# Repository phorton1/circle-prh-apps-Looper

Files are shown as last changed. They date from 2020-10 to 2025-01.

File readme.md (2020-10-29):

# rpi Bare Metal Looper

This repository contains the source code and other information required to
build a bare metal rPi based Audio Looper.

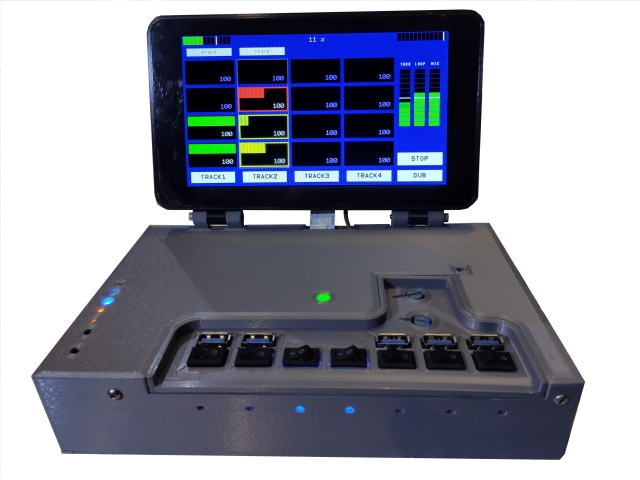
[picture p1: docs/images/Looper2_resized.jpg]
Looper2


Please see the **[docs/readme.md](docs/readme.md)** file for
the [documentation](docs/readme.md) regarding this project.

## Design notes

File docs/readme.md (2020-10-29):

# rpi Bare Metal Looper

**Home** --
**[Hardware](hardware.md)** --
**[Software](software.md)** --
**[UI](ui.md)** --
**[Protocols](protocols.md)** --
**[Details](details.md)** --
**[Looper1](looper1.md)** --
**[Looper2](looper2.md)**

This repository contains the source code and other information required to
build a bare metal rPi based Audio Looper.

Looper2
*Looper2*

This project brings together what, until now, have been multiple disparate parts of the puzzle,
and is a milestone in my **[rPi bare metal vGuitar rig](https://hackaday.io/project/165696-rpi-bare-metal-vguitar-rig)**
hackaday project.

It is based on my prior projects (repositories) which include my fork of the
**[circle](https://github.com/phorton1/circle)** rPi bare metal C++ framework,
and my extensions to it, including a port of the Teensy Audio library to
rPi bare metal, in my **[circle-prh](https://github.com/phorton1/circle-prh)** repository.

The box (my bare metal rPi development environment) also has a Teensy 3.2 board
in it (for serial communications with, and control of, the rPi).  So the
**box** ALSO includes the **[teensyPiLooper](https://github.com/phorton1/Arduino-teensyPiLooper)**
*INO program* which runs on the Teensy 3.2 in it's own repository.
The teensy communicates with, and controls, the rPi, as well as commmunicating with my
3D printed teensy 3.6 MIDI controller pedal, the
**[teensyExpression Pedal](https://github.com/phorton1/Arduino-teensyExpression)**
via serial data.

Together these projects, along with a **Fishman Triple Play** pickup and an **iPad**
running *Tonestack* and *SampleTank* inside of *AudioBus*, form an **actual working rig**.
A set of physical, working hardware, that I can take to a gig, put on the floor, plug in,
and use to play guitar with *effects*, a *midi synthesizer*, and controllable *live loops*
with a user interface (foot pedal) that I like, and that can be somewhat easily extended
and programmed.

Above is a photo of the most recent 3D printed version of the Looper.  There have
been several phsyical iterations of the *box* and the *software continues to
be developed*.

## Organization of Documentation

This *readme* presents some basic concepts and a glossary.  The bulk of
the information about the *Looper* is found in the following separate
readme files and directories:

- **[Hardware](hardware.md)** - Describes the physical hardware
   implementation, which **includes** the specific **sound card**
   I am using, the *Audio Injector Octo*, as well as the **separate teensy 3.2**
   running the *[teensyPiLooper](https://github.com/phorton1/Arduino-teensyPiLooper)*
   INO program.

- **[Software Architecture](software.md)** -
    Describes the overall architecture of **this** C++ program (the *Looper*), which
    runs in an environment that includes **[circle](https://github.com/phorton1/circle)** and
    **[circle-prh](https://github.com/phorton1/circle-prh)** extensions.

- **[User Interface](ui.md)** - Describes the window, buttons,
   and overall **behavior** of this *Looper* from an end-user perspective.

- **[Protocols and Communication](protocols.md)** - Describes, in more detail
   how **communication** with the *Looper* happens, particularly the two way
   communications it has, via serial data, with the
   *[teensyExpression Pedal](https://github.com/phorton1/Arduino-teensyExpression)*.

- **[Implementation Details](details.md)** - Describes
  implementation details of the *Looper* including things like
  the overal **process management** of the program, and details like
  how **crossfading** in looping works.

- **3D Printing** - The folder **"/3DP"** in this repository contains the
  **Fusion360** and **STL** files as well as the *Prusa Specific* printing
  profiles in **3MF** format and **gcode** files*. See the Looper1 and
  Looper2 readme files, below, for more information.

- **[Looper1](looper1.md)** and **[Looper2](looper2.md)** -
  Contains details about the
  contents and construction of the specific instances of the *Looper* box I have
  created, which all generally use the above hardware implementation,
  sofware architecture, and communication protocols, presenting the same user
  interface, but which differ only in their **physical contents**, and ***context***,
  within my overall
   *[rPi bare metal vGuitar rig](https://hackaday.io/project/165696-rpi-bare-metal-vguitar-rig)*
  project.

### Please Also See

- my **[rPi bare metal vGuitar rig](https://hackaday.io/project/165696-rpi-bare-metal-vguitar-rig)**
hackaday project.
- my fork of the **[circle](https://github.com/phorton1/circle)** rPi bare metal C++ framework
- my extensions to circle, including a port of the Teensy Audio library to
rPi bare metal in the **[circle-prh](https://github.com/phorton1/circle-prh)** repository.
- the **[teensyPiLooper](https://github.com/phorton1/Arduino-teensyPiLooper)**
repository which contains the small INO program that runs on the Teensy 3.2
- my 3D printed teensy 3.6 MIDI controller pedal, the
**[teensyExpression Pedal](https://github.com/phorton1/Arduino-teensyExpression)**

## Note on Terminology - "Looper"

The term ***Looper*** is highly overloaded.

It can refer to a piece of software, i.e. a program like *Quantiloop* running on
a consumer computer like an *iPad*, or it can refer to
a dedicated standalone consumer *hardware looper*,
like a Boss Foot Pedal or the looper integrated into a guitar multi-effects device ...
or in my case, it can refer to an *instance of the 3D printed box* I have made that sits on the floor,
***OR*** an *abstraction* of the sum of all the electrical hardware and software
programs running inside that box, **taken as a whole**, or even a more, specific
*part of this software*, the **Looper program** in ***this*** repository, which runs in
bare metal on a *Raspberry Pi*.

Sorry! It's not my fault!

I will generally, in this discussion, use the term *Looper* to loosely refer to the
program, the software, in **this** repository.

In detailed discussions the word
also may occasionally be used synonymously with  a specific **part of *this
software*** ... the *"loopMachine"* as defined in the **Looper.h** and **loopMachine cpp**
files, is sometimes referred to as *"the Looper"* in discusions and/or source
code comments.

At least I can disambiguate a little of it.

When I refer to **Looper1** or **Looper2**, I am talking about the instances
of the 3D printed box I put on the floor.  They are **not** really different in
their basic architecture and/or use of this code.

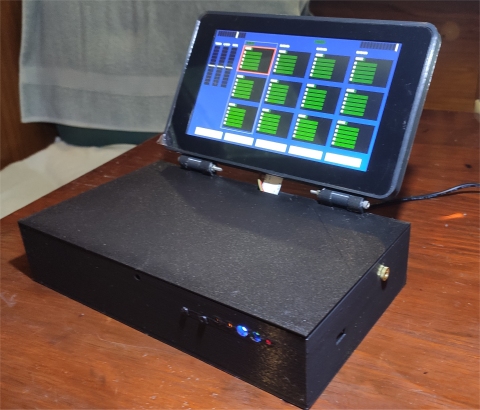
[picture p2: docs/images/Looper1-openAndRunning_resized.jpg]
Looper1-openAndRunning

*Looper1*, running a previous version of this program.

The main difference between *Looper1* and *Looper2* is that *Looper2*
incorporates what was previously an external USB Audio Device, and an external
USB router, ***INTO*** the physical 3D printed box.  This eliminated (at least)
one piece of external hardware from my **rig** and goes to the architecture,
and the realization of a milestone in my
**[rPi bare metal vGuitar rig](https://hackaday.io/project/165696-rpi-bare-metal-vguitar-rig)**
hackaday project.

*But* the difference between Looper1 and Looper2 **is not signficant** in
a discussion of **this repository**, and the program herein.  The same basic
programs run, and the same software, hardware, protocols, and so on, are (were)
used in/with both of them.

## Basic Concepts - Glossary

  The *Looper* consists of four **tracks** that can record and play sequentially, each
  with four *layers* of **clips**, that can play simultaneously at any given time.

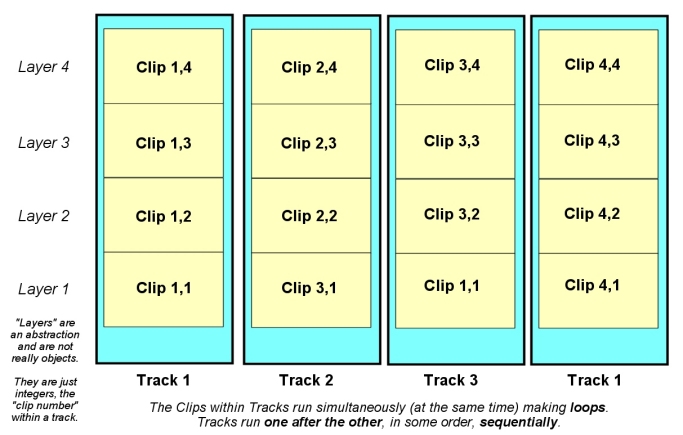
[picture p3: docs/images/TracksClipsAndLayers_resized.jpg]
TracksClipsAndLayers


  This conceptual arrangement of *tracks, clips, and layers* applies not only to this
  program, and it's user interface, protocols and communication, and implementation,
  but also to my other closely related project, the
  *[teensyExpression Pedal](https://github.com/phorton1/Arduino-teensyExpression)*,
  which shares these concepts, and some important **constants** with this program.

  - a **clip** represents a single piece of recorded sound. A clip can be *empty*,
  or it can be *recording*, or it can be *recorded* AND *playing* or *stopped*.
  - a **track** represents upto four clips that are recorded and/or can play together
  synchronously, at any given time.
  - the **layer** of a clip is it's position within a track.

  *The number of tracks and clips are **constants** in the code. 4x4 works well
  for me at this time, with the given screen real estate, and the controllers
  I use, but it is relatively easy to to modify those constants in the code
  to larger, or smaller valus.*

### Clips versus Tracks

  *Clips* play simultaneously, in parallel while *tracks* play sequentially, at
  different times.

  The idea behind *tracks* is that you can have separate **loops** (sets of *clips*)
  for different parts of a song, for example, the INTRO, VERSE, CHORUS, and END
  of a given song. And you can record them, and play them back, in various orders,
  to **build up**, and **perform** a live-looped song.

  Only **one track** is playing, or recording, at any given time.  Generally, when
  a track is playing, *all the clips in it are playing simultaneously*, though each
  can be have different *volumes* and/or be individually *muted*.

  A track is *playing* if any clips within it are playing. A track is *recording*
  if a clip within it is being recorded. A track can be simultaneously playing
  and recording at the same time.

  A track is *running* if any clips within it are recording or playing. The currently
  *running* track is referred to as the **current track**.

  A track is *empty* if all the clips in it are empty.  A track is *stopped*
  if it has at least one recorded clip and is not *running*.

  ### Base Clip, Integer Multiples, and Loop Points

  The first clip recorded in a track is **special**.  It is called the **base clip**,
  and is unconstrained in length.

  **You determine** the length (duration) of the *base clip* when you record the first
  clip in a given track. *Subsequent clips* recorded in a given track **must be** (are) **an
  integral multiple** of the *length* (duration) of the *base clip* in that track.

  A clip **loops** when it is playing and it reaches the end and jumps back to the beginning.
  This is generally called a ***loop point***, and the *loop point* of the *base clip* is
  somewhat special, as it will always be the **next** *loop point* encountered while any
  track is playing.

  Because the clips are integral multiples of the base clip in length (duration), they will,
  generally, synchronize to their beginnings in a predictable manner.  Yet, because you can
  record *different integral multiples* for each clip, they do not necessarily all *loop*
  **together** to the *common beginning* at the same time.

  But eventually they do, as a function of the multiples used. If the numbers are all the same,
  the song will have a rigid predictable structure.  If they are all different, you can build
  songs that don't seem as repetitive to the audience, which take advantage of the different
  clip lengths.

  However, regardless of the actual integral multiples used, algorithmically, eventually
  all clips will cycle back to synchronize to their beginning at some point in time.

### Looper Commands and Pending Commands

  The *Looper* can be issued certain **commands**, for instance to begin recording a track,
  or to begin playing one.

  There is a concept of the **selected track** which can be different than the current track.
  Once again, the currently *running* (recording or playing) track is referred to as the
  **current track**.

  Some *Looper Commands* **may not take place immediately**.

  For instance, if ***Track1*** is *playing* and ***Track2*** is *empty*, and you
  desire to record on Track2, you issue the **Track2 Command** (press the Track2 button) sometime
  while Track1 is playing.   Instead of immediately stopping Track1 and
  beginning to record Track2, the looper will **wait** until it reaches the next
  *loop point*, allowing the base clip (phrase) to complete before stopping Track1
  and beginning to record Track2.

  For that duration, during that window of time, these are called **Pending Commands**.

  While the command is pending, the *current track* is playing, but the *selected track* can be
  said to be **pending** a state change.  Thus, in this example, at the moment you press the Track2
  button (issue the *Track2 Command*), Track2 **becomes** the *selected track* ... different than
  the current one, Track1 (which is *playing*) ... and Track2 is said to have a  *"pending state"*
  ... namely that it is *PENDING RECORDING*.

  This distinction, between the *selected* and the *current* track, and the notion of
  **Immediate** vs **Pending Commands** and a track's *pending state* are important to
  understand, as the are reflected throughout the project(s) in the user interface and
  implementation.

### Layers versus Clips

  This is a relatively minor detail.

  Generally these terms are used somewhat interchangably depending on context.

  The **layer** of a clip is it's position within a track. This is
  an abstraction of a horizontal *slice* of the above diagram.

  There are no *objects* for *layers* in the system, but there ARE objects for
  **tracks** and **clips**.

  In practice, a *layer* is usually just an *integer* that
  identifies a clip within a track, and is also sometimes
  called *the clilp number*.

### Personal Note

I can, **finally**, present the overall architecture
of the system!

It is complicated.

This, for me, is a substantial documentation effort.

I hope to follow it up with some **YouTube videos** demonstrating the *Looper*.

Thanks for visiting this page.  I hope you find it entertaining and/or useful.

-- Patrick

**[Home](readme.md)** --
**Hardware** --
**[Software](software.md)** --
**[UI](ui.md)** --
**[Protocols](protocols.md)** --
**[Details](details.md)** --
**[Looper1](looper1.md)** --
**[Looper2](looper2.md)**

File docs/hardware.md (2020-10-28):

# Hardware - rpi Bare Metal Looper

**[Home](readme.md)** --
**Hardware** --
**[Software](software.md)** --
**[UI](ui.md)** --
**[Protocols](protocols.md)** --
**[Details](details.md)** --
**[Looper1](looper1.md)** --
**[Looper2](looper2.md)**

This readme file describes the physical hardware
implementation of the *rPi Bare Metal Looper*, which *includes* the specific **sound card**
I am using, the *Audio Injector Octo*, as well as the **separate teensy 3.2**
running the *[teensyPiLooper](https://github.com/phorton1/Arduino-teensyPiLooper)*
INO program.

## rPi3B+, AudioInjector Octo, and Official Raspberry Pi 7" Touchscreen

Below shows the basic stack, with the rPi on the bottom, and the Octo on top.

The RCA ports for the Octo have been routed out the back of the box, and the
Touchscreen ribbon cable and power supply positioned to allow the screen to
move on the hinges.

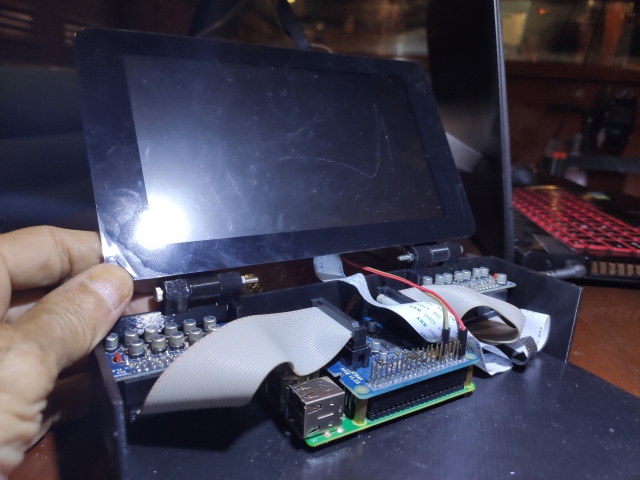
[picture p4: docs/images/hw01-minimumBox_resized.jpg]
hw01-minimumBox


This prototype, early version, shows, essentially, the minimum physical
configuration necessary to run this *Looper* program, or other applications
like this that make use of the *circle-prh* framework. You want a **screen**
of some kind, and a *pointer* input device (the HDMI port and a 40" television,
with a USB mouse were used for most of the development), and a
*high quality sound card* that does *bi-directional* audio.

Getting it down to the **7" touchscreen**, in a box I can put on the floor,
really cleared things up for me.  When I (finally, after more than
a year of development) hooked up the 7" Pi Touchscreen, it basically
worked the first time, within the Circle framework, with no, or
only very minor changes to my code.

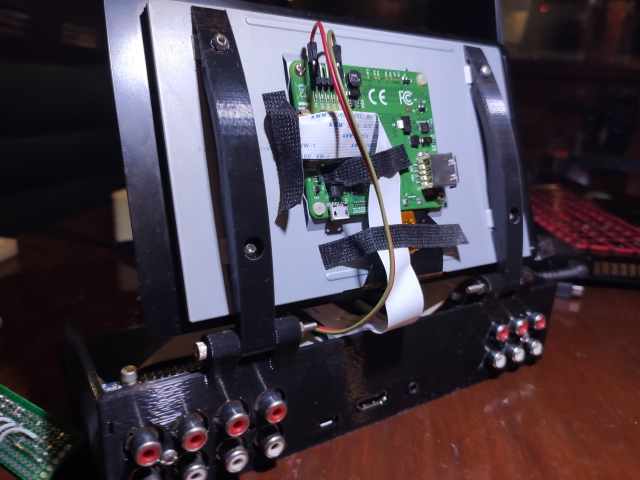
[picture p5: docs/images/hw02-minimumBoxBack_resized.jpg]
hw02-minimumBoxBack


In the above photo you, on the back of the box can see the **8 RCA outputs** from, and the
**6 RCA inputs** to the Octo, and the holes where the rPi micro USB **power** attaches,
and holes for the (unused) rPi HDMI and headphone jacks.

***TODO: I should** publish an analysis of the pin usage by the AudioInjector
Octo, even better yet, a kicad circuit diagram for the rpi, octo, and teensy.
It was hard to ferret out which (other) pins on the rPi I could
reliably use.   In fact, a discussion of I2S might be appropriate here.*

One ***could*** compile the code in this repository, and just *hook the rPi, Octo,
and touchsreen together*, stick the **kernel.img** on an SD card, and it
*would/should* boot and run the *Looper Program*.
 *I am considering publishing a pre-built **kernel.img** "distro"*.

## Teensy 3.2, indicator LEDs, and buttons

I'm not a big fan of swapping SD cards in and out of the rPi. So,
for better or worse, very early on the *circle* project I developed
my own **boot-loader** for the rPi, written in Circle, that can
(among other things), accept a new **kernel.img** over the serial
port, run it, and/or store it on the SD Card for the next reboot.

Historically, I have used a teensy 3.2 as a *smart*
substitute for a typical rs232 usb dongle for serial
(debugging) comms with the rPi.  A hardware serial
port on the teensy is connected to the rPi, and the teensy
serves to forward bi-directional serial text (among other things),
between the rPi and the teensy's *standard* USB Serial port
on my Windows machine.

This architcture (and circuit) goes back to my
[TeensyPi Breakout Breadboard](https://hackaday.io/project/166117-teensypi-breakout-breadboard)
**hackaday** project, and is essentially, with minor changes, a
copy of the breadboarded circuit
from that project.

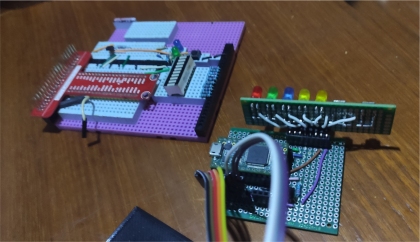
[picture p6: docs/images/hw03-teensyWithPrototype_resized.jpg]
hw03-teensyWithPrototype


Included in this circuit is the ability for the teensy to **reboot the rPi**,
by grounding it's *RUN* (reset) pin.
The circuit uses a **transistor** to control the grounding
of the rPi's *RUN* pin via one of the teensy's GPIO
output pins.
In addition to adding the *header* for the *RUN* pin to the
**rPi board**, I also had to cut a small *notch* into the side
of the **Octo circuit board**, fortunately into the *ground plane*, so that
I could *access* that RUN pin while the Octo is plugged in on top of the
rPi as a *hat*.

#### Hardware relation to Development Environment

This is some more context for the teensyPi evolution and
why this board is part of my *standard application development*
environment.
For what it's worth, my circle **bootloader** interfaces with
a perl program on my Windows machine, the putty-like **CONSOLE**,
that also can work with the Arduino Development Environment,
opening and closing the com port as necessary to prevent
conflicts.

The CONSOLE notices when I have recompiled *kernel.img*.  It tells the
teensy to *reboot the Pi*.  When the Pi reboots, my *bootloader*
runs first (as **recovery.img**) and displays a message (over the serial port)
something like ...

    "hit return to send kernel - will boot existing kernel in 3 seconds .."

... which the CONSOLE program then "sees" and, in response, sends a carriage
 return, and then procedes to the send the kernel.img to the Pi via
 the teensy with a binary serial protocol.
 If the bootloader does not see a carriage return (character 0x0d = 13) in
 three seconds, it just goes ahead and loads and begins running the kernel.img
 from the SD card.

### LED Circuit Board

**In any case**, all of my bare metal rPi projects include this basic
**teensy circuit**, and a couple of *buttons* and some *LED indicators*.

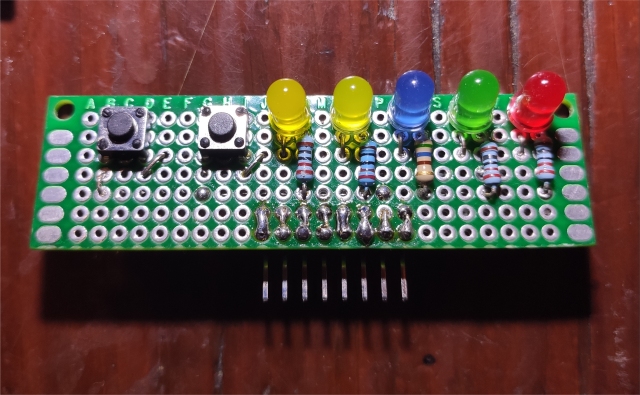
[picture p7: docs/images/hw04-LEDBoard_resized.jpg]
hw04-LEDBoard


The buttons are, from left to right:

- **reboot** the Pi
- put the Teensy in **program mode**

The LEDS, from right to left, are

- **red** - flashes when the teensy is **alive** (copy of the "standard" Arduino/Teensy pin13 onboard led)
- **green** - follows the rPi **RUN** signal where *HIGH* (on) means the rPi
  RUN (reset) pin is "high" (and the **rPi is  running**), or *LOW* (off),
  for brief periods of time, meaning we have brought the rPi "RUN" pin LOW and
  are in the process of rebooting it.
- **blue** - shows the state of the rPi GPIO pin 25, which indicates  that the *std_kernel*
  has **started correctly** .. that
  the *"application"*, the *"program"*, in this case the *Looper* ... the *kernel.img* ...
  has booted correctly  and is **"ready"**. This rPi GPIO pin is **monitored** by the teensy ...
  it is an *input* to one of the teensy's GPIO pins.
- **yellow** - the two yellow LEDs are connected directly to two GPIO pins (12 and 16) from the rPi.
  They *do not go through the teensy*.  Those two LEDs are used by the *AudioSystem* to indicate
  that it is properly processing **I2S** interrupts and buffers, and will flash on and off
  every 90 interrupt/buffers or so (they should flash "on" about 2 times a second).

Please see the [Software](software.md) readme for more info about the **std_kernel** and
the **AudioSystem**

### Teensy Circuit Board

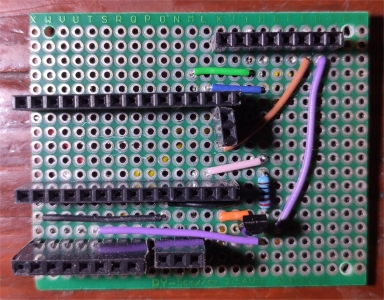
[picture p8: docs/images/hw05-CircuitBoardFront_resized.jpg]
hw05-CircuitBoardFront

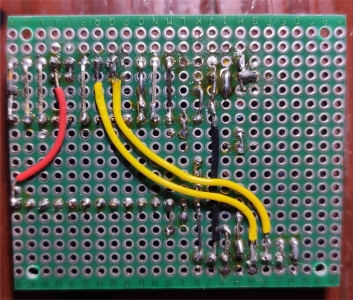
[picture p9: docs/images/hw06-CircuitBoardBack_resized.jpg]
hw06-CircuitBoardBack


The teensy circuit board, in the "top" image above, has connectors for

- 8 pin connector to the **LED/Button Board** at the *top right*
- two rows of 14 pin connectors, and a sideways 2 pin connector, for the **teensy 3.2**
  and it's **program pin** to plug into, in the *center*
- an 8 pin connector to connect to the *rPi* via the **teensy-rPi connector**, at the *bottom left* and
- *next to it*, a 3 pin connector for a second hardware serial port, that is brought out to the
side of the box to a 1/8" jack, that is used to connect to the
*[teensyExpression Pedal](https://github.com/phorton1/Arduino-teensyExpression)*,
as shown below.

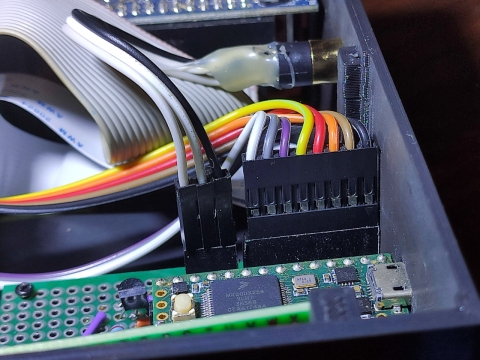
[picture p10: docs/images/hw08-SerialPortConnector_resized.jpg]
hw08-SerialPortConnector


I also had to add a pin to the teensy to bring the *PGM* **program** signal down
to the teensy circuit board, where it can be connected to the button on the LED board.

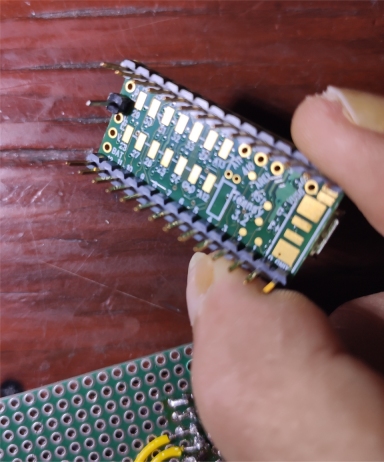
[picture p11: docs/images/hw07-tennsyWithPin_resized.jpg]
hw07-tennsyWithPin


### Teensy-RPi Connector

I kind of like how this connector came out.  I have long struggled with how to
make one-off connections to the top of an rPi stack.

I started by sticking some nylon supports and a **female header** on the pins
from the *Octo*:

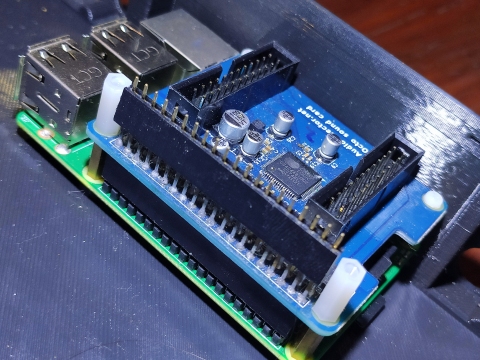
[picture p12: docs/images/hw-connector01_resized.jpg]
hw-connector01


Plunked a small circuit board on top of it:

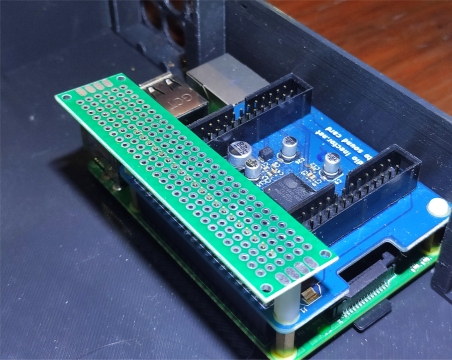
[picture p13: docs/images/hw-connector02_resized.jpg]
hw-connector02


Then cut it to size ....

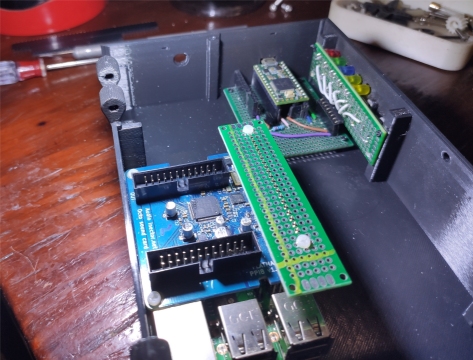
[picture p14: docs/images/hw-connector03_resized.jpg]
hw-connector03


*Note that in the above image you can see the **notch**
that I cut into the *Octo circuit board* to be able to get to the *RUN* pin
on the rPi*.

I then used that circuit board to create a connector between the rPi and the
teensyCircuit board that I can fasten securely with nylon screws.

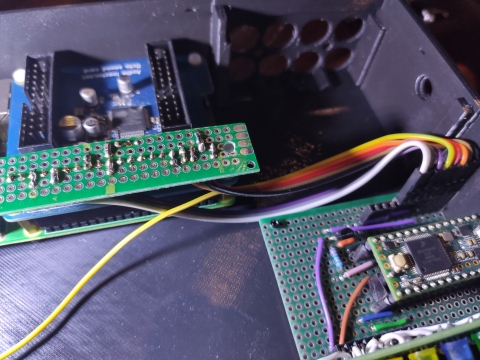
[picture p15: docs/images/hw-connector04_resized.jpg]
hw-connector04


by soldering standard, pre-made wires with *dupont male connectors* on one end,
which I then combined into a **single 8-pin plug** that connect to the *teensy
circuit board*.

The **yellow** wire trailing off to the bottom left in the above photo goes
from the *connector* to the *RUN* pin on the rPi, and then through the cable
to the *teensy circuit board*.

The connector also has two pins (you can't see, on the underside) for the
**power** to the *rPi touch screen*.

## Final (initial) Assembly

Below is a photo of the basic components assembled together in the
initial *instance* of the physical 3D printed box, [Looper1](looper1.md),
running an earlier version of this *Looper* program.

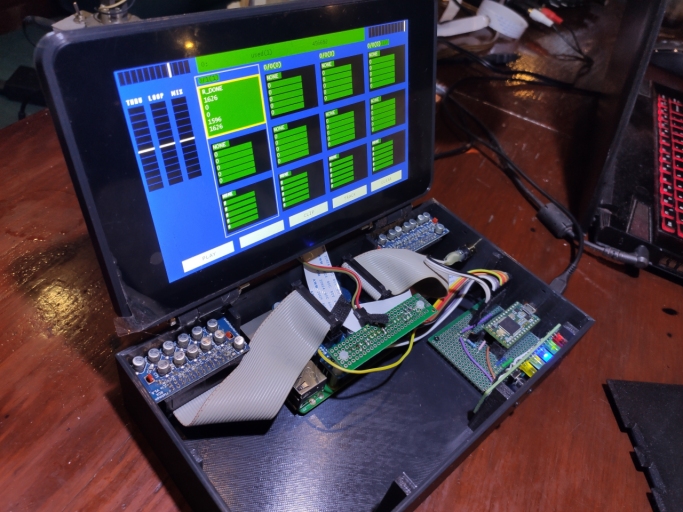
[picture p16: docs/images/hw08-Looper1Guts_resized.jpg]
hw08-Looper1Guts


*--------------- end of hardware.md --------------------*

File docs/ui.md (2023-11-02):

# User Interface  - rpi Bare Metal Looper

**[Home](readme.md)** --
**[Hardware](hardware.md)** --
**[Software](software.md)** --
**UI** --
**[Protocols](protocols.md)** --
**[Details](details.md)** --
**[Looper1](looper1.md)** --
**[Looper2](looper2.md)**

This readme file describes the **User Interface** of the *rPi BareMetal Looper*,
including the window, buttons, and overall **behaviors** presented by the program,
from a user's perpective.

The looper **touchscreen** display shows most of the salient features of the UI
and can be used to control (and describe) most of the *behaviors* of the looper.
*However, there are aspects of the Looper's **behavior** that are not accesible
via the touchscreen and which are only available via **LoopCommands** over the
serial port*.

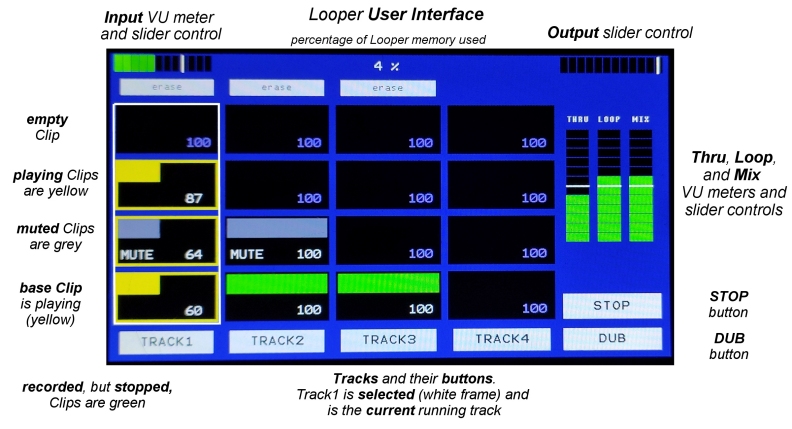
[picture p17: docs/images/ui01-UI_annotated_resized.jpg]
Looper UI


## UI Basics

**VU meters and slider controls** - there are *VU meters* with touch sensitive
*sliders* for the **Input**, **Thru**, **Loop**, and **Mix**.  The final **Ouput**
control is merely a slider ... it does not have a VU meter. You move the *white bars*
on the VU sliders by *touching and dragging* them to adjust the various volumes.

**Buttons** - there are *buttons* for the **four tracks**, the **Stop** and
**Dub** buttons, and, for *recorded* tracks, **erase** buttons above the tracks.
Buttons can be *pressed*, and some can be *long-pressed*, or *pressed twice*
for different behaviors.

- the behavior of the **Track Buttons** will be described in detail, below.
- **Long Pressing** either the *Stop* or *Dub* buttons **stops** and **clears the looper**.
- the **Stop** button does not show until the loopMachine is *running* (a clip
  is *recording* or *playing*).
- A *short click* on the *Stop* button will cause the loopMachine to stop
  *at the next **loop point***, finishing the current phrase (*base clip*)
  before doing so.
- Once the *Stop* button has been pressed (in other words, while the stop command is *pending*),
  the button label changes to **STOP!** (with an exclamation point).  Pressing
  it (again) at this time will cause the looper to **stop immediately**.
- the **erase** buttons do not show until at least one clip is *recorded* or
  *recording* on the given track.  If the track is recording, a *short press*
  on the erase button will **abort** the recording (but keep playing the other
  clips on the track, if possible).
  A *long press* on on one of the erase buttons will **erase the track**, and if
  it is the *current* playing or recording track, will stop the loopMachine.

Clips and Tracks

- The **currently selected track** is highlighted with a *white frame*.
- Clips have a solid frame that matches their *state* and/or that **flashes**
  if they are *pending* a state change.
- Clips that are *playing* or *recording* have a **bar** that moves from left to right
  as the the looper runs.
- Clips that are **solid green** are *recorded*, but *stopped* at this time.
- A Clip with a moving bar that is **red** (not shown above) is *recording*.
- A Clip that is *pending reording* will have a **flashing red frame** (with no bar).
- Clips with moving bars that are **yellow** are *playing*.
- Clips that are *pending play* have a **flashing yellow frame** and a solid green bar.
- Clips that are *pending stops* have **moving yellow or red bars** and a **white flashing frame**.
- Clips that are **muted** are shown in **grey** (looks like grey-blue in above photo)
  and have the word *"MUTE"* in the lower left portion of the clip.
- Each Clip shows it's **volume** as a number from 0 to 127, where *100 means
  unity gain* (no volume change).

Touchscreen on Clips

- **pressing** (clicking) on a clip will *mute* or *unmote* it
- **pressing and dragging up or down** on a clip will change it's volume

Memory Usage

The *Looper* shows the percentage of memory used at the top of the screen.
*As currently implemented, I am conservatively using **128M** (about 1/8th
of the rPi3B's **1GB**) of RAM for the Looper.*  This allows for **1440 seconds**
(about 20 minutes) of recording stereo clips in the Looper for a given song,
which should be enough for most uses. *The constant **LOOP_HEAP_BYTES** in
Looper.h can be changed to increase this if desired.*

### Touchscreen UI versus Serial Midi control

Each of the active UI elements above, the *volume sliders*, the *track buttons*,
the *erase buttons*, the *dub* and *stop* buttons, can also be controlled via
**serial midi data**.  In fact, the touchscreen UI is *implemented in terms of*
**Loop Commands** and various other entry points to the loopMachine, loopTrack,
and loopClip *objects*.

For example, pressing the **Track1 button** causes the **uiWindow** to issue the
**TRACK1** *Loop Command*. to the *loopMachine*.   This *exact same behavior* can
be effected by sending the *serial midi data* for LOOP_COMMAND_TRACK1 to the
serial port of the *Looper*.

To comprehensively describe the **behavior** of the *Looper* it is best to
describe it in *abstract terms* that apply both to the *touchscreen UI* and
the *serial midi protocol* it accepts, especially since there are *aspects
of the Looper behavior that are currently only availalbe via serial midi
data* and which are NOT reflected in the touchscreen UI.

So when we refer to *pressing a button* we are also describing the behvior
when the LoopMachine *responds to* certain **serial midi** "commands" (messages),
and typically, vice-versa.

## Loop Commands

Here is a list of the existing *Loop Commands*.  These are the core functions of the *Looper*.

- **CLEAR_ALL** (corresponds to a *long-press* of either the *Dub* or *Stop* buttons) - stops the
*Looper* if running and clears (**erases**) all tracks and clips.  It also resets all
*clilp volumes* to 100, and clears the *mute* state of all clips.
- **TRACK1-4** (corresponds to pressing one of the four *track* buttons) - will be explained more, below.
- **STOP** (corresponds to the first press of the *Stop* button) - issues a **pending stop** command
  to the *currently running* Track (clips) if any, which will then stop gracefully at the next *loop point*,
  or, if *recording a base clip* to **immediately stop** and save the recording.
- **STOP_IMMEDIATE** (corresponds to the "second" press of the "Stop" button) - stops the
  *Looper* **immediately**, aborting any *recording* currently in progress.
- **DUB_MODE** (corresponds to a press of the "Dub" button) - tells the *Looper* that the
  **next** *TRACK1-4 command* should **record** instead of *playing*
- **LOOP_IMMEDIATE** (not currently reflacted in touchscreen UI) - causes all Clips in the
  currently running Track to **imemdiately** jump back (loop) to their starting points.
- **SET_LOOP_START** (not currently reflacted in touchscreen UI) - sets a **mark point** that
  the Clips will begin looping back to when they reach the next *loop point*.  This lets you
  create a *sub-phrase* **within** a Track, and loop it (without otherwise altering the cilps
  themselves).  This can be used, for instance, at the end of a song, as is common,
  to repeat the last part of the chorus 3 times before ending.
- **CLEAR_LOOP_START** (not currently reflacted in touchscreen UI) - clears any existing **mark points**
  for the selected track. All tracks **mark points** are **automatically cleared** upon any track
  change, and, of course, when the Looper is cleared.
- **ABORT_RECORDING** (corresponds to a *short click* of one of the *erase* buttons while a clip is recording) -
  abort the current recording, if any.  If there are other *recorded* playing clips in the track, the track
  will continue *playing*.  If not, the *Looper* will stop immediately.
- **ERASE_TRACK1-4** (corresponds to a *long click* of one of the *erase* buttons) - **erase**
  the given track, so that it can be re-recorded from scratch.  If the given track is the
  *current* playing or recording track, the *Looper* will stop **immediately**.

### LOOP_COMMAND_TRACK1-4

The **core functionaity** of the looper revolves around
pressing one of the four **Track** buttons (or sending
one of the four *Track Loop Commands* to the Looper via *serial midi*).

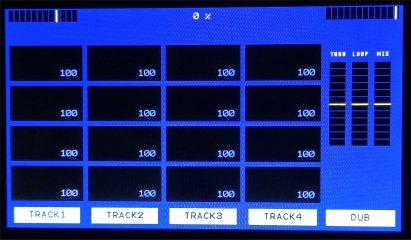
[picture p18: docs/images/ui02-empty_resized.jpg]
empty

*Empty*

The *behavior* (what happens) when one of these commands (buttons) is issued (pressed)
depends on the **state** of the Looper (and the state of the *Dub* button) when the command is
issued.

- From a *stopped or empty looper*, pressing one of the four track button on an
  *empty* track will cause that track to **begin recording** the *base clip*
  for that track.

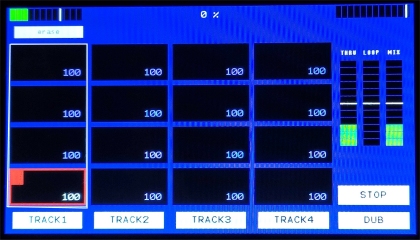
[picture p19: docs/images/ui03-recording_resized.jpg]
recording

*Recording base_clip*, after pressing **Track1** first time

- Pressing the *Stop* button while recording a *base clip* will *determine
  it's length* (duration), save the recorded track and **stop** the Looper immediately.
- Pressing the **same** track button while recording it's *base clip* will
  *determine the clip's length* and **immediately** save the recording and begin
  *playing it* (start *looping*).

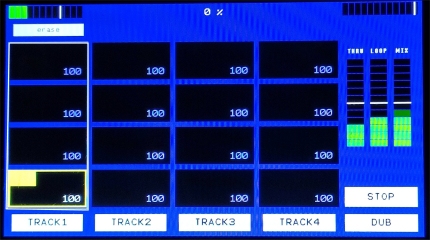
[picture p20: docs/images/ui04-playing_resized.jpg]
playing

*Playing* (looping), after pressing **Track1** second time

- Pressing a **different** track button while recording a *base clip* will
  *determine it's length* and **immediately** save the recording. If the
  **newly *selected*** track is *empty* it will **immediately begin recording**
  it's *base clip*.   If the new track has content, it will **immediately
  start playing**.

Basically, from an *empty or stopped Looper*, or while recording a *base clip*, the
Track buttons (commands) act **immediately**.

- If the Looper is **stopped** (with some *recorded* clips), pressing one of the
Track buttons for a track that has content will cause it to **immediately** begin
*playing* that track.
- Pressing the Track button for an *empty* track on the *stopped* looper
will cause that track to **immediately** start recording the *base clip*
for the track.

### The "Dub" button - Recording a second Clip within a Track

As we pointed out, pressing the **same Track button** while recording the
*base clip*, or pressing a Track button on a track with content while the
Looper is stopped, will cause the Track to start *playing* (looping).

**But what if you want to record another Clip on the track?**

The answer is that you first press the **Dub button** *before* you press
the *TrackN* button.  If the Dub button is lit up (has been pressed)
it turns **orange**, and will take effect on the next Track button press.

So, for example, from an empty looper, to *record( Clip(1,**1**)* and then
to immediately start *playing* Clip(1,**1**) and *recording* Clip(1,**2**), you
would press the following buttons (issue the following *commands*):

- **Track1** - first press *starts recording* the *base clip* for track 1.
- **Dub** - pressing the Dub button sets the **one shot** *dub mode* for
the next Track button press.  The Dub button turns **orange**.
- **Track1** - the second press of the Track1 button **immediately**
starts *playing* the *base clip* WHILE *recording* the **2nd clip** .

The *Dub* button is a **one-shot** button.  It is **not** a *mode*.
Once the command takes effect, the *Dub button is cleared and
will no longer be **orange** (active)*.  You have to press it
*every time* you want to overdub.

### Otherwise, TrackN commands will be pending commands

The *Looper* will enforce the rule that **all clips in a track
have a duration (length) which is an integral multiple of the
base clip duration**.  So, after the *Track1-Dub-Track1* button presses
in the previous section, if you then (more or less) immediately
pressed the *Stop* button, while the base clip
was playing, **the looper would not stop**!

In the below image, within the white framed Track, the **frames around the clips** are **flashing**
yellow and red.

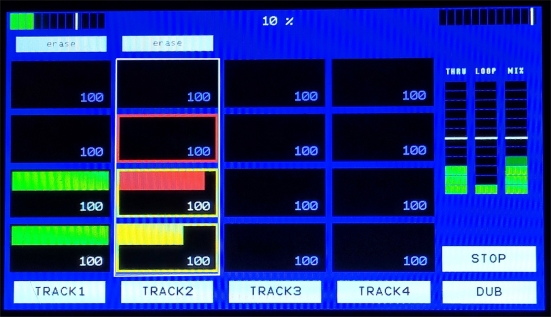
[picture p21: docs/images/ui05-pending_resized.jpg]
pending
 *Pending Clip States*

In the above photo, the yellow *base clip* is playing, the red *clip2* is recording, but *both*
have flashing yellow frames indicating that they are **pending playing** at the next loop point,
and *clip3* is **pending recording** with a flashing red frame.

It will keep *recording* Clip2 until the *loop point*, then it will
start recording the Clip3 the flashing will stop.

This behavior also happens when you click *a different* **Track** button.

*When the base clip is playing* the Looper is said to be **looping** and
all **Track Commands** are executed as *pending commands* ... they take
effect upon the **next** *loop point*.

So, for example, if you have **two recorded tracks** and are playing one
of them, you press the *other track button* well *in advance of* when you
will start jamming over the next track.  This *fire and forget* behavior
is **really handy** so that, except for the *base clips*, you don't have
to be concerned about the **exact timing of your button presses** when
building and jamming over live loops.  You just press the button
any time during the *playback of the base clip* and at the next
*loop point* the Looper changes Tracks, and starts plsying and/or
recording the (clips on the) next Track.

You can even **change your mind** about button presses after performing
them because **only the most recent issued track command will happen
at the next loop point**.   So if you accidentally pick the **wrong Track**,
or decide that you **really don't want to record another clip**, you can
effectively **cancel** or change the command by pressing one of the
track buttons, including the track button for the currently playing
or recording track, ***as long** as you issue the new command
before the **loop point***.

### Loop Commands not reflected in the Touchscreen UI

There are a couple of *Loop Commands* that are not available, at this time, via the touchscreen.
It would be easy to add buttons for them to the *touchscreen UI*, but *I don't really
**use** the touchscreen UI*, except, generally, for *testing the Looper*.
My actual use of the Looper is via **serial data** to and from the
*[teensyExpression **foot** Pedal](https://github.com/phorton1/Arduino-teensyExpression)* which
sits on the floor.

Those *Loop Commands* not available in the UI are:

**LOOP_IMMEDIATE** - causes all Clips in the currently running Track to **imemdiately**
  jump back (loop) to their starting points.   You use this when you want to repeat
  *just the beginning* of a Track one or more times.

**SET_LOOP_START** - sets a **mark point** that the Clips will begin looping back to
when they reach the next *loop point*.  This lets you create a *sub-phrase* **within**
a Track, and loop it (without otherwise altering the cilps themselves).
There are a lot of songs that have a *CHORUS* where, at the end of the song, you
need to **repeat** *part* of the CHORUS, a single phrase, three times, and then you end
the song.

So, for example if you had recorded a **Track** for
*"Mary had a little lamb who's fleece was white as snow"*, and
at the end of the loop you wanted to repeat the *"white as snow"*
sub-phrase three times, then stop, you would:

- **be** *playing* the Track to begin with
- when it gets to the word *white* the first time, you would press the *SET_LOOP_START* button, then ...
- when it gets to the *loop point* (the end of "snow"), the Looper will go back to the
"white as snow" sub-phrase, **instead** of jumping back the beginning of the loop.
- That will start the *second* time through. After that ....
- You let it loop one more time, and then press the *Stop* button **any time** during
the *third*, final, time through, and ....
- the Looper will come to a stop after the word "snow".

The *LOOP_IMMEDIATE* and *SET_LOOP_START* commands (buttons) can be used together
*albeit manually* to **repeat the middle of a Track**.

With *automation*, as takes place in the
*[teensyExpression's](https://github.com/phorton1/Arduino-teensyExpression)*
**songMachine**, interesting pre-programmed sequences of behaviors of the Looper
can be orchestrated that would not otherwise be possible by manually pressing
buttons.

### Other Serial CC "commands" and "notifications"

For completeness, there are also **serial midi** surrogates for the other
functionality of the *Looper UI* including, setting the overall *volume levels*,
and/or the *mute/unmute* state and *volume* of the individual clips, as well
as to be **notified** when the *state* of the looper changes.

Those are defined programatically in **commonDefines.h**

```
// Looper Serial CC numbers             // TE       rPi         descrip
#define LOOP_COMMAND_CC        0x01		// send     recv        the value is the LOOP command
#define LOOP_STOP_CMD_STATE_CC 0x02		// recv     send        the value is 0, LOOP_COMMAND_STOP or STOP_IMMEDIATE
#define LOOP_DUB_STATE_CC      0x03		// recv     send        value is currently only the DUB state
#define NOTIFY_LOOP            0x05     // recv     send        value=number of pending loop notifies
#define LOOP_CONTROL_BASE_CC   0x08     // both     both        RANGED for 0..LOOPER_NUM_CONTROLS the value is the volume control (Looper pedal == 0x67)
#define TRACK_STATE_BASE_CC    0x10		// recv     send        RANGED for NUM_TRACKS, upto 16 tracks, value is track state
#define CLIP_VOL_BASE_CC       0x20		// both     both        RANGED for NUM_TRACKS * NUM_LAYERS, upto 32 total - value is the clip volume
#define CLIP_MUTE_BASE_CC      0x40		// both     both        RANGED for NUM_TRACKS * NUM_LAYERS, upto 24 total - value is mute state
	// this leaves a little space for expansion from 0x60 to 0x7f
```

These are sent, or received, by the *[teensyExpression pedal](https://github.com/phorton1/Arduino-teensyExpression)*
to control the *Looper* and/or change the **state** (the LEDs of the buttons, screen, etc) **of the foot pedal** so
that it shows what's happening with the *Looper*.  For example, the *teensyExpression* has
Track1-4 buttons, just like the *Looper* and those buttons, with addressable colored LEDS,
that can be set to green, yellow, or red, and/or can **flash** just like the *frames around clips
on Looper screen*. This provides a completely separate, yet consistent, floor based (foot pedal),
User Interface to the Looper.

As of v2.11 there is a new LOOP_COMMAND

```
#define LOOP_COMMAND_GET_STATE			0x30	  // NEW the looper will dump all state
	// dumping the state will send
	//      LOOP_STOP_CMD_STATE_CC
	//      LOOP_DUB_STATE_CC
	// 		TRACK_STATE_BASE_CC for NUM_TRACKS
	//		CLIP_VOL_BASE_CC for NUM_TRACKS * NUM_LAYERS
	// 		CLIP_MUTE_BASE_CC for NUM_TRACKS * NUM_LAYERS
	// We do not currently send
	//		LOOP_CONTROL_BASE for LOOPER_NUM_CONTROLS(6)
	// Because TE just always pushes the volume controls
```

Which will send all of the state from the Looper to TE.

*-------------- end of *ui.md* ---------------------*

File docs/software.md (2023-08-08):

# Software Architecture - rpi Bare Metal Looper

**[Home](readme.md)** --
**[Hardware](hardware.md)** --
**Software** --
**[UI](ui.md)** --
**[Protocols](protocols.md)** --
**[Details](details.md)** --
**[Looper1](looper1.md)** --
**[Looper2](looper2.md)**

This readme describes the **Software Achitecture** of the **rPi BareMetal Looper**.
which runs in an environment that includes **[circle](https://github.com/phorton1/circle)** and
**[circle-prh](https://github.com/phorton1/circle-prh)** extensions.

**This repository** contains the *Looper* program, which is a specific *application*, using
specific subsets of the circle and circle-prh repositories (libraries). *Much of this discussion
could be compartmentalized into the other referenced repositories, but for the time being
I am trying to present a single, understandable, overall architectural description of
**how it all works**, rather than trying to minimize my documentation footprint!*

*When this is done, I will **probably** upddate (add) more generalized architectural
discussions to those other repositories,*

## Basic Architecture

The *Looper Application* consists mainly of an **Audio System Device**, the *loopMachine*, and a
single **wsTopWindow**, the *uiWindow*, which constitutes the *user interface*.  The
**loopMachine** has four (4) **loopTracks** which each own four (4) **loopClips**.

Likewise the **uiWindow** has four **uiTracks** which each have four **uiClips**.

Between the *loopMachine* and the *user interface* there is an abstraction layer of
the *loopMachine* called the **publicLoopMachine**, with it's corresponding **publicTracks**
and **publicClips**.  The *User Interface* **can only see** the *publicLoopMachine*.  It has no
visibility of, or direct access to the *loopMachine*.

The **loopMachine** runs all the time as an *interrupt driven audio system device*, therefore
it is very important that it runs quickly, and in a known state. The objects
in the *loopMachine* have *API's* that are visible to each other as appropriate to implement the
core behavior of this interrupt driven *Looper*, but that are **not** visible to the UI.

The **pubicLoopMachine** is a set of pure virtual base classes that are implemented by the
loopMachine, and available to the UI, that carefully grants **readonly** access to
the state of the loopMachine, with **specific methods** (*entry points*) that the UI
can call, like the ***publicLoopMachine's command()*** method to *change it's state*, to cause
the *loopMachine* to actually **do** something.

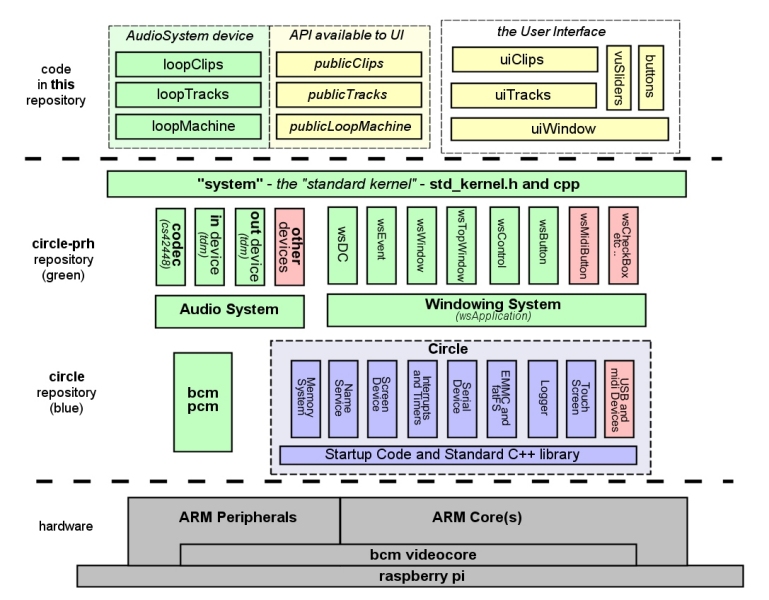
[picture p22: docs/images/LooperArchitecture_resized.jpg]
Looper Architecture


Below the top dashed line you see the **circle-prh** and **circle** libraries/repositories.  Some
of the boxes in that diagram are in **red**, indicating, and implying, that there is (much)
code in those libraries that does not happen to get used in this specific application.

The other boxes are **examples** of the specific objects and kinds of code that are used
from those libraries, and do not reflect an *exhaustive* list of the specific objects and
code.  But this diagram does show the most important parts of those libraries to this application,
including the use of three of the specific *"prh*" subsytems (subdirectories):

- the **Audio System**, the objects within (above) it, and below it, the important common **bcmpcm** (cpp & h) object.
- the **Windowing System**, and some of the objects within it, and ...
- at the top, the (overloaded name) **system** subdirectory, which contains the
basic framework (*"glue"*), the *standard kernel*, in **std_kernel.h and cpp** that
ties everything together into *applications* written in this environment.

By the way, when all of this code is built (compiled and linked) it results in a *single file*
named **kernel.img** (the exact name depends on the rPi model), which is then copied (somehow)
to the SD Card on the Raspberry Pi, and which is then subsequently booted.  In other words, every
complete *application*, at this time, in this sytem, is built and run as an
**operating system kernel** in common parlance. *There is **no linux** or other
operating system involved*. That's why we call it **bare metal**!!

**ALL of the code** running on the rPi is in these three repositories.

In **circle** the most important objects (classes) necessary to build a complete
program (**kernel.img**) in this system, includes (but is not limited to):

- the **CMemorySystem** - initializes the rPi memory system (MMC)
- the **CDeviceNameService** - provides for named devices
- the **CScreenDevice** - the HDMI or rPi screen device
- the **CInterruptSystem** and **CTimer** - basic interrupts and timers
- the **CSerialDevice** - the rPi UART driven serial port
- the **CEMMCDevice** and *addOn* **FATFS** classes for the SD Card
- the **CLogger** - a generalized Logging device to Screen or Serial ports
- the **CTouchScreen** - the VideoCore, or other, TouchScreens

Once again, to point out, I included some **red** boxes in the diagram to specifically
show that we are **not** using all of the code in the circle-prh and circle libraries.

For example, in **circle-prh** we are not making use of many of the *AudioSystems*
devices that are availble, including **mixers**, **reverbs**, and so on,
nor many of the **WindowSystem** objects that are available like **checkboxes**,
**midi buttons**, and so on. Nor are we inluding anything from entire *"prh** subdirectories,
including the **devices**, **lcd**, and/or **bt** subdirectories, in this specific application.

In fact, my intention was/is to keep the *Looper* program as simple as possible.

In *circle* I specifically am *NOT* using the circle **USB** capabilities (for performance
reasons), nor the **USB Midi Device** that it makes available.  There is a *ton* of other
functionality in circle that I am not using ... including any of it's *sound devices*,
or it's entire approach to audio, either of it's two available *entirely different*
addon *windowing systems*, or many of it's other *add on* extensions. Above is merely a list
of the most important circle objects that we **are** using in this build.

Finally, at the bottom, below the lower dashed line, is the **hardware** itself, abstracted
in this diagram to the notion that there are one or more **arm cores** (cpus) available to us,
depending on the model of raspberry pi used, but that all of them include
the **arm peripherals** which are the low level programming API's and protocol to things like
*I2S* and *UARTs*, supported by the chip, and that all of **that** runs on top of the
(mysterious and undocumented) Broadcom **VideoCore**, which is a separate CPU on the
**Raspberry Pi** board.

## The BCM_PCM and the AudioSystem as used in this application

Perhaps the most important object in the *AudioSystem* is the **bcm_pcm** object (h and cpp files).

The **bcm_pcm** provides an interface to the BroadCom *PCM Peripheral*, and implements
a generalized approach to the **I2S** (*Inter IC Sound*) protocol to interface the **rPi** to
various **sound cards**. It uses **DMA** to send and receive *buffers* of sound data
to and from the sound card based on **interrupts**.

In this application we are using the *AudioInjector Octo* sound card.
The *Octo* is a 6 (six) input, 8 (eight) output sound card.

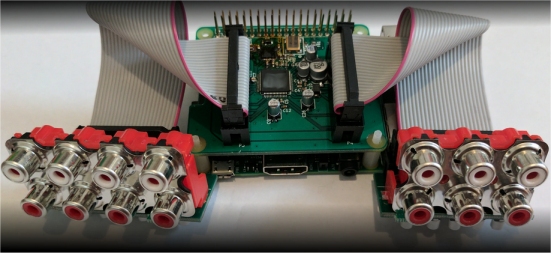
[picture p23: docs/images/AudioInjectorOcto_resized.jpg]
AudioInjectorOcto

*AudioInjector Octo sound card*

In this application we are only using two
of the input channels and two of the output channels (the *Looper* is **stereo**),
but underneath the hood, the system is *processing* the data for all 6 input channels
and 8 output channels.  The *Octo* runs as a (pseudo) **TDM** (time division
multplexed) device. We are running it at **44.1 khz** with **16 bit** samples,
and a **buffer size** of 128 samples **times** eight (8) channels.

The *initialization* of a sound card takes place in the **control** device, so in
this case the, with the cs42448 based *Octo*, we are using the **control_cs42448**
(h and cpp) device in our system.  When using this control device, you also need
to use the **AudioInputTDM**  and **AudioOutputTDM** devices from the *AudioSystem*.

The *bcm_pcm* generally handles the buffering of input and output data, using *DMA* on
an interrupt driven basis.  When it has received an input buffer, it then proceeds
to pass it to the *Audio System*, either directly in a single core system, or via
an inter-processor interrupt in a *multi-core Circle* application.   The *Looper*
is built as a multi-core appclication running, at this time, on a **raspberry Pi 3B+**.

The *bcm_pcm* (and all rPi interrupts) runs on **core 0**.

The *application* registered the specific *control* and *TDM* input and output devices
with the AudioSystem. It also registers the *loopMachine* (which is, itself, a stereo
*Audio Device*) during **setup()**. The AudioSystem runs on **Core1**.

When the bcm_pcm *hands off* the buffer to the AudioSystem, it then,
in turn, passes it to the registered **AudioInputTDM** device.

The **AudioInputTDM** device then de-multiplexes the data into a set of per-channel
buffers. Plese note that at this time, in this application, at this level of
processing, the system is **actually** processing the entire set of *6 input channels*.
When the *input_tdm* has prepared the buffers, it in turn passes them to the
back to the AudioSystem, which passes them to the registered *loopMachine*.

This *loopMachine* is only interested in, only uses, the first *stereo pair*
of input buffers available to it.  It works with those buffers, possibly
*recording them* by copying them off into RAM someplace (in *looperClips*), and
produces the final stereo output pair of buffers by processing the input buffer
**thru** to the output, applying volume levels and noting the minimum and maximum
values in the buffer(s) for the vu meters. It also possibly mixes previously
recorded buffers (**playing** *looperClips*) into the stream, likewise
applying volume levels and noting values for the vu meters,
finally resulting in a pair of **output** buffers that it (the *loopMachine*)
passes back to the *AudioSystem*.

The *AudioSystem* then passes those final buffers to the **AudioOutputTDM** device
where that object multiplexes the data back into I2S buffers, and provides those back
to the *bcm_pcm* for output to the sound card via I2s.

## Application Initialization and basic UI Framework

In this *typical* application, the **standard kernel** handles (makes) the
various calls to the AudioSystem and WindowSystem (does the *process management*
in the system) to orchestrate the overall behavior and functionality of
the program.

With regards to the *WindowSystem* (the **user interface**), the system first calls a
specific method, **wsApplication::Create()** that the *application must supply* that
**instantiates** the user interface.

**This** application (*Looper*) merely instantiates the *uiWindow* object
with the following small piece of code in **app.cpp**:

```
void wsApplication::Create()
{
    LOG("wsApplication::Create(%08x)",this);
    new uiWindow(this,ID_WIN_LOOPER,0,0,getWidth()-1,getHeight()-1);
}
```

The uiWindow then creates the objects within it (the *uiTracks, uiClips, vuSliders*,
and *wsButtons*) and returns.

Looper UI

wsWindows, and objects derived from them, implement an **onDraw()** method that the
system can call.

Once the *Top Level Window* is intantiated, the *system* ensures that it is drawn
on the screen at the correct time (by recursively calling wsWindow's **onDraw()** methods),
and that it (the top level window) receives *wsEvents* (like EVENT_CLICK) via it's
**handleEvent()** method.

*wsWindows* also have a method called **updateFrame(()** that is called frequently
(30-100 times a second or more) separate from events, that constitutes the **ui thread**.

The *uiWindow* uses calls to it's *updateFrame()* method (which it in turn passes
to *updateFrame()* methods on the *uiTrack* and *uiClip* objects) to query the
*pubicLoopMachine* and corresponding *publicTracks* and *publicClips* for state
changes that must be reflected in the user interface.

For example, a uiClip displays a "moving" *"bar"* that represents a
recording or playing track in progress, that changes, and must be redisplayed, as
the recording or playback progresses, based on the value of **publicClip's**
*getRecordBlockNum()* or *getPlayBlockNum()* methods.
Likewise, uiTrack displays a frame around the the *selected* track (based on
calls to **publicTrack's** *isSelected()* method, and uiClip shows **pending commands**
by flashing the frame around a uiClip on and off in various colors (red for *record*,
yellow for *play*, and white for a pending *stop*) based on the **publicClip's**
*getClipState()* method, combined with the value returned by the **publicLoopMachine's**
*getPendingCommand()* method.

Note that windows do not draw themselves from within the *updateFrame()* method.
They merely **update** their state, and if they need to be redrawn, they set their
own **WIN_STATE_DRAW** bit, and at a later time, in a coordinated manner, all windows
with that bit set will be redrawn (have their *onDraw()* methods called) by **the system**.

## Audio System Initialization and Framework

As noted in the **[circle-prh](https://github.com/phorton1/circle-prh)** repository,
this **port of the teensyAudio system to the rPi** exposes an *Arduino-like* approach
to the instantiation and initialization of *AudioSystem* objects.  AudioSystem objects
can be *statically* or *dynamically* allocated.

The **system** (*std_kernel.cpp*) calls the static global **setup()**
method once at the start of the program.

*There is also a familar Arduino-like static global **loop()** method,
that runs on the AudioSystem thread (*Core1*), and IS called, but this method is
generally left **empty** in my typical applications, as we want the AudioSystem
to run un-impeded.  Remember that the **UI** (WindowSystem) runs on a **different
core**.*

The AudioSystem *setup()* method is in the file **audio.cpp**,
and looks something like this:

```
#include <audio\Audio.h>
#include "Looper.h"

AudioInputTDM input;
AudioOutputTDM output;
AudioControlCS42448 control;

loopMachine *pTheLoopMachine = 0;
publicLoopMachine *pTheLooper = 0;
    // static global pointers to objects available, by convention, with
    // externs in Looper.h, to the loop machine itself, or to the
    // more limited "public" UI version of the object

void setup()
{
    pTheLoopMachine = new loopMachine();
    pTheLooper = (publicLoopMachine *) pTheLoopMachine;

    new AudioConnection(input,      0,      *pTheLooper,       0);
    new AudioConnection(input,      1,      *pTheLooper,       1);
    new AudioConnection(*pTheLooper,   0,      output,         0);
    new AudioConnection(*pTheLooper,   1,      output,         1);

    AudioSystem::initialize(200);

    pTheLooper->setControl(LOOPER_CONTROL_OUTPUT_GAIN,0);
    pTheLooper->setControl(LOOPER_CONTROL_INPUT_GAIN,0);
}
```

Though there are other things in the *Looper's* **audio.cpp** file, like
**#defines** that let you choose the other available *Codec* and *Input/Outtput devices*,
and the fact that the **setup()** method, after executing the above code,
then goes on to *fade up* the input and output gains to their default values,
the above is, more or less, all that is necessary for an *application* to instantiate
and initialize the *AudioSystem*.

#### **loopMachine specifics - commands and pending commands**z

The *system* will call the loopMachine's **update()** method once per the *interrupt cycle*
of bcm_pcm-I2S *input buffers*. The loopMachine  processes those buffers, and at the end of
update(), calls it's own virtual **transmit()** method to *"send them back"* to the
AudioSystem, who will then eventually send them to the *AudioOutputTDM* device, which
in turn multiplexes them and gives them to the *bcm_pcm* to send out to the sound card
via *I2S* on the next output interrupt.

The other *main input to the loopMachine* is (by the uiWindow calling)
the *publicLoopMachine's* **command()** method.

The *command()* method will be called by the UI, typically in response to a
button press, but also, in detail, in response to the uiWindow receiving some
**serial midi data** via the rPi SerialPort, which it *monitors* in it's
**updateFrame()** method.

One way or the other, though, to the UI and external clients, *the (public)LoopMachine is
essentially an interrupt driven black box state machine*.  You merely pass commands to it,
for instance to *clear* it, or to *begin recording a clip*, but most of those commands
are handled completely separate from the basic loopMachine **interrupt driven update()**
method, via the **pending command** mechanism.

Remember that the UI is running on one core, and the Audio System on a different one.

We want to make sure the AudioSystem (which is already an interrupt handler)
is not itself *interrupted* or held up in any way.   So, when commands are issued
to the *loopMachine*, they usually result in a **pending command** that
will be processed in the loopMachine's *update()* method at some later
time, typically at a **loop point**.

*Some* commands, like *CLEAR LOOPER* and *STOP IMMEDIATE* are handled immediately.

A list of the commmands that can be issued to the *Looper* can be found in
**commonDefines.h**.

#### **loopMachine controls - volumes and vu meters**

Another set of entry points into the publicLoopMachine are a set of API's
that allow the UI to query and adjust the overall volumes used by the Looper.  There are five
controllable global volumes on the loopMachine.

- **INPUT** - controls the basic (hardware) input gain of the Codec
- **THRU** - controls how much of the input is passed through to the *mix*
- **LOOP** - how loud is the loop (any playing *cips*) passed to the *mix*
- **MIX** - a volume control for the *mix* before passing the buffer(s) to the ...
- **OUTPUT** - hardware output gain of the codec

Most of these volume controls have an associated **meter** API on the loopMachcine
that allows the UI (the *vuSlider* objects) to obtain the minimum and maximum
levels of the given control, over some interval of time, and to display it.

All of the above controls *except the final OUTPUT control* have **meter APIs**
on the publicLoopMachine, associated with them. *We cannot **meter** (monitor) the actual
final OUTPUT values as that takes place in hardware!  But for all of the others,*
the loopMachine::update() method *remembers* the high and low values for
each stage as it processes each buffer, and presents an API
for the UI to read and reset them.

Those methods are *polled* during the **vuSlider's** *updateUI()* method.

Note that, as it does for *Loop Commands* sent via serial midi, the **uiWindow**
also monitors the serial port for **serial midi CC messages** that correspond
to each of the above controls, and converts those messages into the appropriate
calls to the aforementioned loopMachine API's.

#### **loopClip - volumes and muting**

The **publicClips** present an API that allows the UI to obtain,
and/or modify the Clip's individual **volume** level and/or to **mute** it.

A clip is **still running** (playing or recording) EVEN IF IT IS MUTED.

The clip volume and mute state are *applied* when each clip makes
it's contribution, if any, to the *output buffers*, in it's own **update()**
method.

As with the other **serial midi** stuff, the **CC's** for affecting
the individual volumes and mute states is coded in the *uiWindow*,
with constants in *commonDefines.h*,
which maps them from serial midi messages into specific method calls on the
*publicClip* objects.

#### **Serial Midi Notifications** also happen in the uiWindow objects

As the loopMachine is running, changes to it's state (the machine,
tracks, and/or clips), as we've seen, must necessarily be reflected in
the corresponding UI objects.

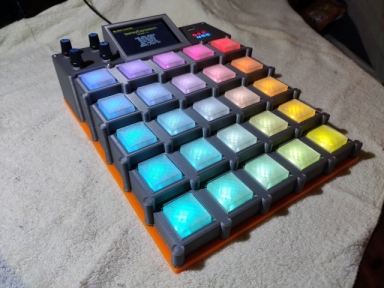
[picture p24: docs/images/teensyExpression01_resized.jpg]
teensyExpression01

*teensyExpression midi controller pedal*

Furthermore, serial clients, like the
*[teensyExpression Pedal](https://github.com/phorton1/Arduino-teensyExpression)*,
in addition to wanting to **control** the loop machine, by *sending* serial
midi commands to the Looper, want to be notified about changes to it's state,
by *receiving* serial midi.  For example, the pedal want's to know
*when a loopPoint is reached* in it's implementation of the **songMachine**,
and it wants to know when a *track state* changes (*empty*, *recording*,
*playing*, or *stopped*) and/or if there is a currently *pending command*.
so that it can **light up** the *track buttons* in various colors, and
**flash** them for pending commands.

Therefore, when the **UI objects** (uiWindow, uiTrack, and uiClip) notice
that something has changed (in their updateState() methods), they typically
will *also* send out a **serial midi notification** message, which the client
device (the **teensyExpression pedal**) can then use to keep track of,
utilize and to display, what's happening with the *Looper*, in real time.

Once again, the specific **CC numbers** and *parameter values* for these notification
methods are defined in **commonDefines.h** (which is  denormalized to, and
included in the *[teensyExpression Pedal repository](https://github.com/phorton1/Arduino-teensyExpression)*.

## Other General Notes

#### **Other sound cards could be used**

I chose the *AudioInjector Octo* because, to me, it sounded the best of any
audio cards I tried to work with on the raspberry pi.  The fact that it has
a whopping 6 inputs, and 8 outputs, is viewed merely as a *bonus*.

The *AudioSystem* also currently has support for the *AudioInjector Stereo* in
**control_wm8731.h and cpp** as well as the *teensyAudio Card* in **control_sgtl5000.h
and cpp**, and either of those *should* be usable with this *Looper*.

It should also be relatively straight forward to implement *other sound cards* into
this system and application.  I am just not aware of many others that do both **input**
and *output*. *If you know of a **great** sound card that does both input and output on the
raspberry Pi, I would like to hear about it!*

#### **This is a general *Audio Application* development platform**

This *Looper* project is but one of the possibiities that could be written
using this set of libraries. Especially to the degree that the *AudioInjector
Octo* presents 6 inputs and 8 outputs, it could also be viewed as a
**audio application development platform** for developing other
rPi based audio "devices".

A couple of examples come to mind.

First, please note that the rPi3B+ has **four cores** and that at this time
we are only using *three* of them.   **Core0** is dedicated to interrupt processing
and inter-process communications.  In this program Core0 doesn't actually *run* anything ...
it just waits for, and processes, interrupts.
The *AudioSystem* runs on **Core1**, and the *WindowingSystem* (UI thread) runs
on **Core2**.

So, at this time, **Core3** is unused, and available.

It might (*should*) be possible, and practical, to implement, for example, a set
of **guitar effects** that run on Core3, that do not impact the current behavior
or timing of this *Looper*.

And/or, within this basic framerwork, by *expanding* the *loopMachine*
and/or adding objects (like the existing *Audio System* **reverb** and/or **mixer**
devices) to create a Looper which, itself has *effects*, and which works on, and with,
the entire 6x8 (six by eight) set of inputs and outputs, for example, to let you
**separately** loop your **voice** from looping your **guitar** .. or to even have
separate *loop channels* for every member of the band.

The point of this section is that although it works, and I consider it part
of my *rig*, this *Looper* project is **really** just an example of the kinds
of things you *could* build with this system.

*------------- end of softare.md ------------------*

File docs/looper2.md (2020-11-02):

#  Looper2: the latest instance of the box

**[Home](readme.md)** --
**[Hardware](hardware.md)** --
**[Software](software.md)** --
**[UI](ui.md)** --
**[Protocols](protocols.md)** --
**[Details](details.md)** --
**[Looper1](looper1.md)** --
**Looper2**

This readme file describes the most recent instance of the **phsycial 3D printed** box
representing the *rPi Bare Metal Looper*, it's specific contents, and a bit
about how it fits into my overall *[rPi bare metal vGuitar rig](https://hackaday.io/project/165696-rpi-bare-metal-vguitar-rig)*
project.

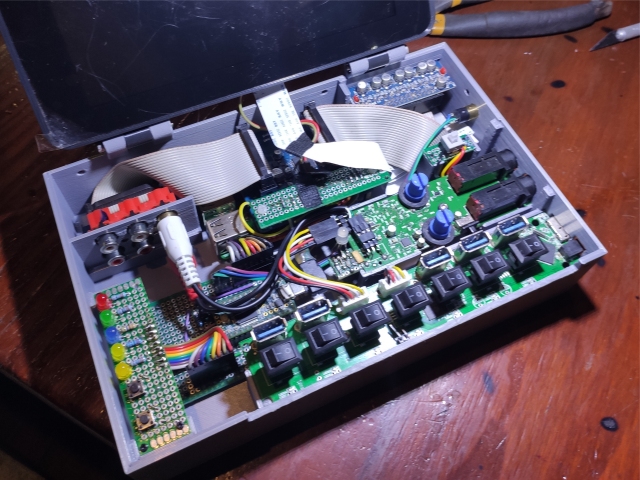
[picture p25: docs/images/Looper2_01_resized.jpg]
Looper2_01


This readme can be viewed as **inheriting** certain information and content presented in
the *[Looper1](looper1.md)* readme.  For instance, in 3D printing **this** box, I used the same
**frame for the rPi official 7" touchscreen** that I had already printed for **that** box, and
it also contains the same basic core components, the **sound card** (*Audio Injector Octo*)
and **teensy 3.2**, as were in that box, ableit in a sligthly different physical configuration.

There was enough room left over in the [Looper1](looper1.md) box that I figured I could
incorporate the **iRig2 HD** USB audio card, and the 7 port **usb hub** from my previous
*(hackaday) [SynthBox1](https://hackaday.io/project/168197-synthbox-1) box (project).* within
this box, and eliminate a piece of hardware and several cables from my live rig.

### Stuff from previous ["SynthBox1"](https://hackaday.io/project/168197-synthbox-1)

I had previously modified the circuit board from an inexpensive **7 port USB hub**
to replace two of the USB port connectors with dupont connectors.  For this
project, I removed those two *dupont* connectors and replaced them with more
secure, real, white *PCB connectors*:

Looper2_11
Looper2_12

Also from that project I took the **iRigHD2 board** which I had *already modified* to
replace the 1/8" audio jack and micro USB connectors with *male headers*,
bring the *Activity LED* to the the "top" by adding a small circuit board extension,
and by adding a *Pad Switch* to allow me to change the impedance of the 1/4 input plug
to work better with my guitar.

Looper2_13 *modified iRigHD board*

Looper2_14 *iRigHD2 Activity LED addition*

Looper2_15 *iRigHD2 Pad Switch Addition*

### Assembly

I then measured everything, did the 3D design work in fusion, and printed a new **box**
for this version.  Notable changes from the previous box include:

- The **RCA inputs** are now internal to the box ... as the audio output of the *iRigHD2*
now connects directly to the *Octo* audio inputs.  This **eliminated an external cable**.
- I added a separate **USB Port** for the
**[teensyExpression pedal](https://github.com/phorton1/Arduino-teensyExpression)**
- The **Teensy Circuit Board** was moved to the left side of the box.   This necessitated
adding a micro-usb "extension" port, as well as reworking the *LED Display board* and
*rPi-teensy connector*
- **supports** for the iRig2HD, the USB router, the Pad switch board, and the new location
of the teensy board and LED display board.

The *3D printing files* (fusion, STL, and gcode) for printing this bo
can be found in the **/3DP** folder of this repository.

Looper2_21

Below is an image showing the removable *SD Card Cover* that lets you swap the SD card
out of the rPi without disassembling the box, and another image showing the new location
of the *Teensy* circuit board along with the *teensy-rPi connector* (from which I have
de-soldered and removed the wires in preparation for modifying them to fit the new
configuration).

Looper2_22
Looper2_23

The first image below shows the *reworked rPi to Teensy connector* on top of the Octo card, and
connected to the teensy.  Also in that image you can see the attached *micro USB extension for the Teensy*
and the *USB Port extension* waiting to be connected to the *USB Hub* and let me plug the
*teensyExpression* pedal into the side of the box.

Looper2_24
Looper2_25

The second image above shows the box with the addition of the *LED Display Board*
(and it's new cable connector), with the *iRig2HD and USB Routers* installed, and you
can see the *1/8 jack* for the additional teensy serial port.

Below is the box with all the *guts* installed, except for the Octo *RCA
connectors* and the *screen*.  It it you can see two 3D printed pieces that
make up the *top* of the box.

Looper2_26

The two parts of the top are glued together with superglue, and then
(after drying) the assembled top is attached to the box with 3mm screws
so it can be removed later as needed.

### Connections

In the below image you can see the connections on the right side
of the box.

Looper2_31

From left to right in the above image, the connectors are:

- **5V** power supply (input) to the USB hub.
- **USB Hub Connector** to the iPad
- the white cable plugged into the **USB Port** to the *teensyExpression pedal*
- the **1/4" Guitar** input
- the **Teensy micro USB connector** and above it,
- the **1/8" Serial Port**,  also to the *teensyExpression pedal*

The USB hub ends up **powering** the *teeenyExpression pedal* and the *iRigHD2*.
The actual *teensy* in **this** box (and the *rPi*) are both powered by the rPi
power connector (not shown here) on the **back** of the box.

*A future iteration of this box will likely consolidate the power supplies into
one connector*.

In the above image, we are **not using** the *left 1/4 jack* which is an additional output from the iRigHD2,
and the *Teensy micro USB connector* is only used during development to communicate
with, and program, the teensy and rPi from my **development machine**.

Looper2_32

And finally, in the above image you can see the full box, running the *Looper* program.
To the *left* you have the vertical column of **LEDs and buttons** for the teensy and rPi,
showing that the program is running correctly, the *center* **iRig Activity LED** (green)
shows that sound is coming into the iRigHD (and not overdriving the inputs, which would cause
the LED to turn red), and a square hole where you can insert a tool to change the **Pad Swtich**.

On the "sunken" portion of the top, that leaves the 5 available *USB ports*, the *7 switches* that control them
and the two gain control *potentiometers* (input gain and output volume) for the iRig.   I have marked
where I like those two pots with a magic marker.

On the front of the box, there are the seven LEDs indicating power to the USB hub ports.
The two blue LEDs show that the power is "on" for the USB to the
*iRigHD* and the *teensyExpression pedal*, respectively.

**TODO: Want an image of the whole rig, with teensyExpression and iPad, here**

*---------------------- end of Looper2.md ------------------------

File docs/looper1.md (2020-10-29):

# Looper1: the initial instance of the box

**[Home](readme.md)** --
**[Hardware](hardware.md)** --
**[Software](software.md)** --
**[UI](ui.md)** --
**[Protocols](protocols.md)** --
**[Details](details.md)** --
**Looper1** --
**[Looper2](looper2.md)**

This readme file describes the first instance of the **phsycial 3D printed** box
I created for the *rPi Bare Metal Looper* and how it fits into my overall
*[rPi bare metal vGuitar rig](https://hackaday.io/project/165696-rpi-bare-metal-vguitar-rig)*
project.

As it came first, the subsequent *[Looper2](looper2.md)* can be viewed to **inherit**
information and content from this instance.

Both make use of, and contains, the general core
*[Hardware](hardware.md)* implementation of the *Looper*.

The **Fusion360** and **STL** files as well as the *Prusa Specific* printing
profiles in **3MF** format and **gcode** files* for this box are in the
**"/3DP"** folder in this repository.

Looper1-openAndRunning

### Looper1 Box, Teensy & LED board, rPi and Octo

Looper1_01

The box **printed** without supports.  The first thing added is the **teensy circuit board** which
has holes for four tiny *self tapping screws*.  Then you insert the 3D printed **switch extensions** into the box,
insert the the **LED board**, and secure it with two more screws.

Looper1_02
Looper1_03

The **rPi3b+* is attached to the box with four **brass supports** with
*3mm threads* that screw into the box.  On top of that, the **AudioInjector
Octo** card is added with *nylon supports and screws*.

Looper1_04
Looper1_05

### "Official rPi" Touchscreen Case and Bevel

The case for the **touchscreen** is also used in [Looper2](looper2.md).

I *removed the four supports* that came with the official touchscreen
and replaced them with **shorter** nylon supports, connected the
**ribion and power cables** and secured the ribbon cable with
some black adhesive tape.

Then the **bevel** is set into place (but not screwed down yet) and
the **back** is attached with four *nylon screws*.  The *back* locks
the *bevel* into place

Looper1_06
Looper1_07
Looper1_08
Looper1_09

Then **hinges** are added with four *3m metal screws* which provides the
structural support for the screen and further locks the *bevel* in place.

Looper1_10
Looper1_11

The assembled *screen* is connected to the *box* with *two 20x3mm* screws.
There are **insets** in the box portion of the hinges for the *two 3mm nuts*.

### Internal Assembly

I then attached the screen's ribbon cable to the rPi.  I **folded** the
ribbon cable and secured it with some black tape.

Looper1_12
Looper1_13

In the second image above, I have added the **RCA connectors** to the
*Octo*.  They are each held in place with two metal 3mm screws inserted
from the back of the box.

Below is an image of the **rpi to teensy** connector I fashioned (see
the [Hardware readme file](hardware.md)), including the final *8 pin
dupont connector*.  Also in the below image (of the underside of the
connector) you can see the *two right angle pins* that will connect to the
screen power supply, and the **yellow** jumper that will connect to the
*RUN* pin on the rPi.

Looper1_14
Looper1_15

In the final image (middle right) above I have also added the **1/8 serial port jack**
and am in the process of connecting the **RUN** jumper.

### Looper1, finished and running!

Looper1_back

Above is the **back** of the *Looper1* box showing, from left to right the

- *8 RCA Outputs* from the Octo
- the rPi *micro USB (power)* connector
- the (unused) rPi *HDMI* connector,
- the (unused) rPi *Headphone Jack*, and the
- *6 RCA Inputs* to the Octo

Below is an image of the *Looper1* **box**, in my running **rig** at that point
in time.  To the upper right, on a mic-stand, you can see the **iPad** running
the *SampleTank* software synthesizer.

On the floor is the
**[teensyExpression Pedal](https://github.com/phorton1/Arduino-teensyExpression)**
along with *four expression pedals*,
and on the first step is this black *Looper1 Box*, along with my earlier, grey,
*(hackaday) [SynthBox1](https://hackaday.io/project/168197-synthbox-1) box (project).*

Looper1_rig

The **grey synthBox** in the above image contains a USB Audio Device
(an *iRig2 HD*) and a 7 port *USB router*.  The router has an *FTP Triple Play*
dongle, and a *USB cable* to the *teensyExpression* plugged into it.

After using *Looper1* for a while, I decided to **get rid of the *synthBox***, and
combine the USB audio device and router with the *Looper* into the
***[Looper2](looper2.md)*** box.  There was a bunch of empty space available,
so the newer box is just abut the same size as the old bux.

This not only *eliminated one box*, and several
cables that I have to bring to gigs, but also
helped to *balance* the box.

With the (heavy) TouchScreen, *Looper1* tended to **tip over**
when the screen was open past vertical, which is where you need it when it's on the floor.
By adding the extra *weight* of the router and iRig to the fron of the box, *Looper2*
does not tip over when the screen is open to usable viewing angles.

*------------------- end of looper1.md -------------------------*

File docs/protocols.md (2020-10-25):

# Protocols - rpi Bare Metal Looper

**[Home](readme.md)** --
**[Hardware](hardware.md)** --
**[Software](software.md)** --
**[UI](ui.md)** --
**Protocols** --
**[Details](details.md)** --
**[Looper1](looper1.md)** --
**[Looper2](looper2.md)**

This readme describes the communication **Protocols**
and general **techniques** used to communicate with the *rPi BareMetal Looper*,
particularly the two way communications it has, via serial data, with the
*[teensyExpression Pedal](https://github.com/phorton1/Arduino-teensyExpression)*.

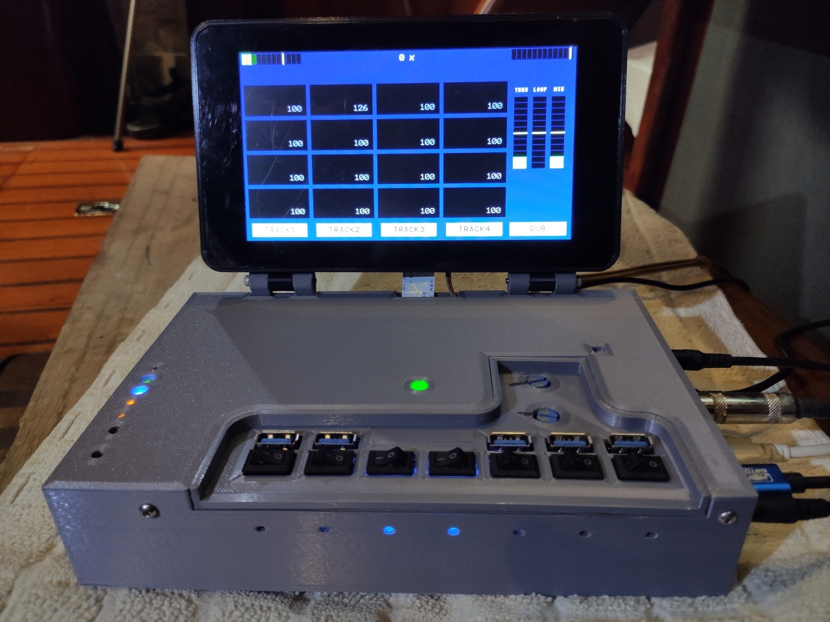
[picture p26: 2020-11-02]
docs/images/Looper2_32.jpg

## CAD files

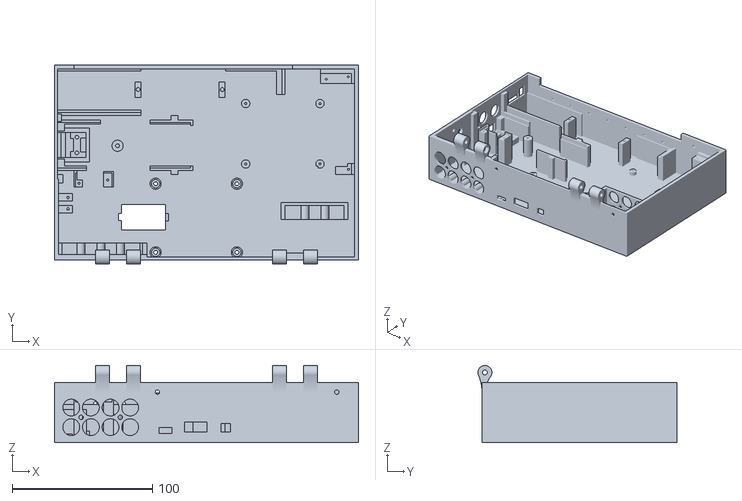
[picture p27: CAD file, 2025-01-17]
3DP/fusion/box.stl
217.0 x 142.2 x 55.0

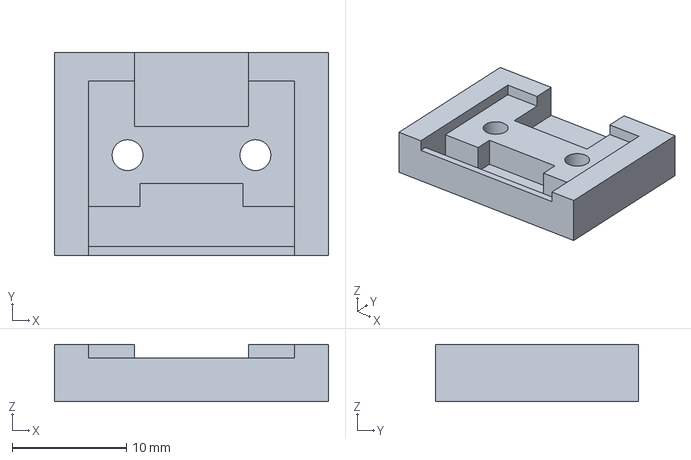
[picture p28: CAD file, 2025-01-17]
3DP/prusa/USBA_TEMP_BASE.3mf
24.0 x 17.8 x 5.00 mm

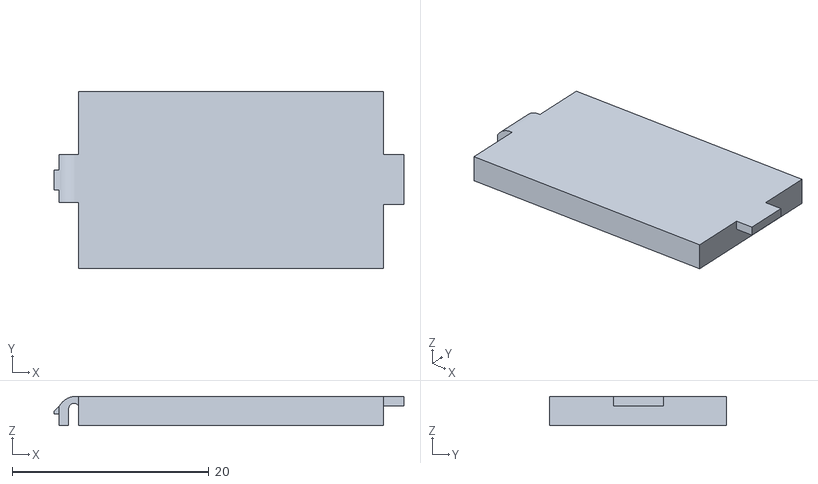
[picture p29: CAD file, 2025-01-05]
3DP/fusion/sdcard_cover.stl
35.6 x 18.0 x 3.00

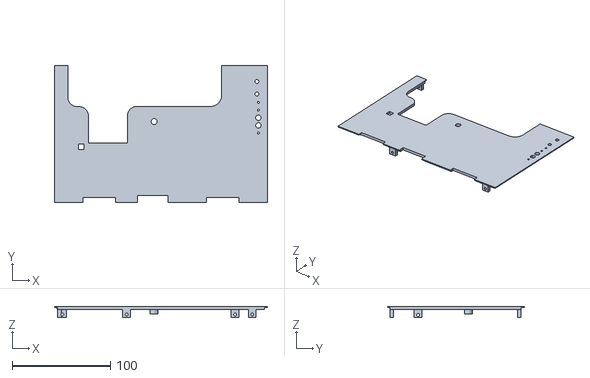
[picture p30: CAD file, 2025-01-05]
3DP/fusion/box_top.stl
217.0 x 139.2 x 11.0

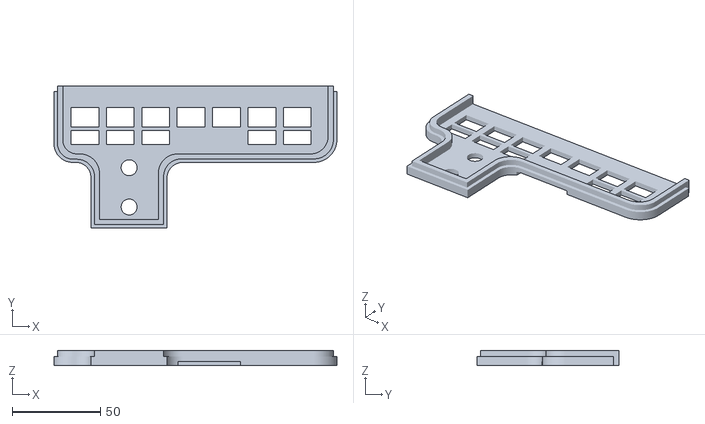
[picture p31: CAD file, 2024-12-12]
3DP/fusion/lowered_top.stl
160.0 x 80.3 x 8.27

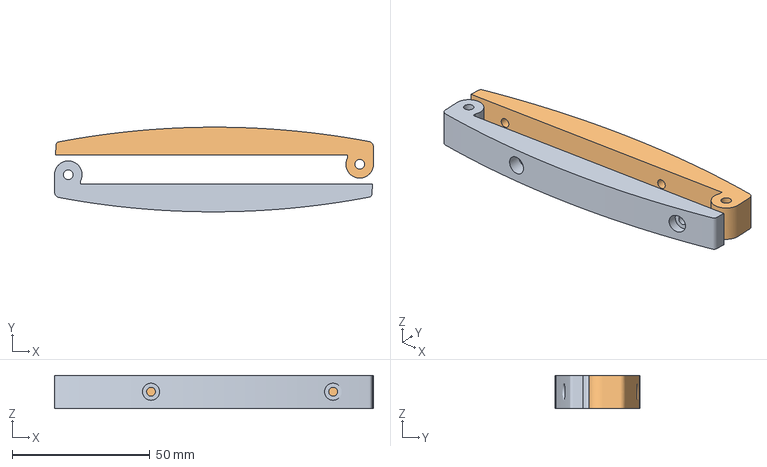
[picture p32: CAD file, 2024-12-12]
3DP/prusa/screen_hinges.3mf
115.6 x 30.7 x 12.0 mm
left_screen_hinge.stl x 2

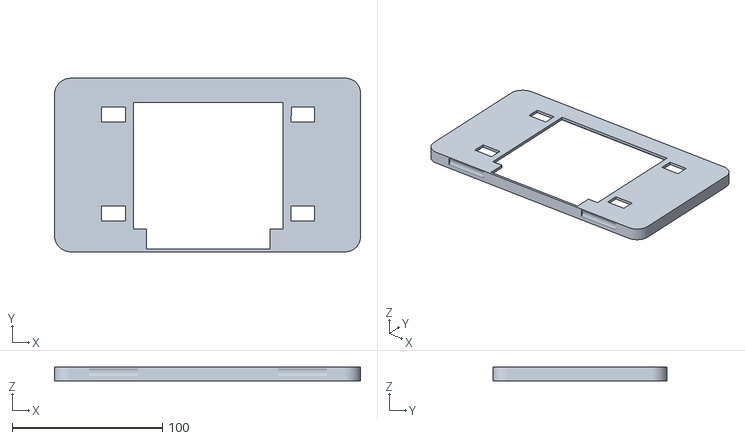
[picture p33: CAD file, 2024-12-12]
3DP/fusion/screen_case.stl
204.0 x 115.8 x 9.30

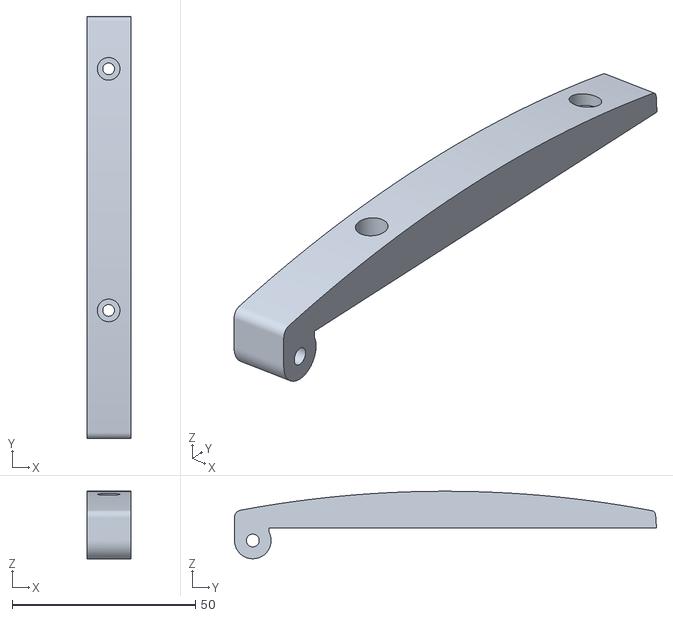
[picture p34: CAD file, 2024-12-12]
3DP/fusion/left_screen_hinge.stl
12.0 x 115.3 x 18.5

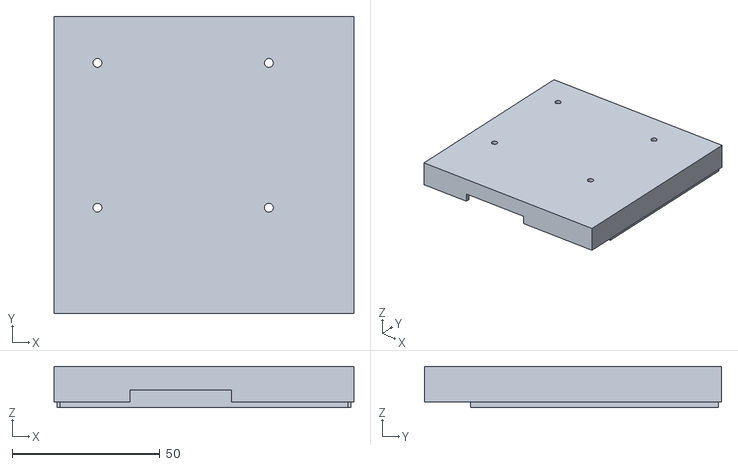
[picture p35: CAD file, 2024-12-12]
3DP/fusion/screen_back.stl
101.5 x 100.5 x 14.0

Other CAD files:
3DP/fusion/USBA_TEMP_BASE.stl
3DP/prusa/box.3mf
3DP/prusa/sdcard_cover.3mf
3DP/prusa/box_top.3mf
3DP/prusa/screen_case.3mf
3DP/prusa/lowered_top.3mf
3DP/prusa/screen_back.3mf
3DP/fusion/2024-12-09-LooperRedraw.f3d
3DP/fusion/2025-01-04-LooperRedraw.f3d
3DP/fusion/2025-01-17-LooperRedraw.f3z

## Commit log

2020-05-11 not MIDI registering uiClip buttons yet
2020-05-11 INITIAL working vuSlider ... I had a severe bug which I first thought was a stack overflow or heap corruption, but ended up thinking that there is a limit to the number of audio devices I can hook up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
2020-05-13 SINGLE LOOPER audio object - changed from using mixers, peaks, etc, trying to find bug. Implemented better vuSlider and knob controls. reworked Update() frame rate. Expanded midi event handling to in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
2020-05-13 INITIAL D-PROBE
2020-08-20 INTERMEDIATE NON-WORKING VERSION - ALMOST does cross fades across a partially implemented single clip in single track AUDIO_FUCKING_NOISE - tried everything (again), turned off USB, reduced screen ac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
2020-09-14 Looper/Teensy Circuit board - Change ports for Looper circuit board
2020-09-19 FIRST INTEGRATED LOOPER AND TEENSY-EXPRESSION TEST Turned on "WITH VOLUMES" to no apparent ill-effect.
    uiWindow is now responding (per updateFrame)
    to the serial port and directly calling looper commands
    or setting controller volumes (bypassing my whole "midi
    subsystem")
    Also note that the loop volume pedal is sluggish.
    A major code cleanup is demanded after a proof of concept
    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
2020-09-25 TE<->RPI SERIAL MIDI CIRCLE: added serial receive IRQ handler to circle code ARDUINO: created teensyPiLooper and cleaned up Serial handling CIRCLE-PRH: implemented interrupt handler recv in uiWindow 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
2020-09-27 WIP - INTEGRATED LOOPER 1.0 - basic buttons and functionality
2020-09-27 implement preliminary USER interface CLIPs are now MUTE buttons with DRAG for volume and send serial MUTE commands status bar shows PCT of memory sused
2020-09-28 SERIAL INTERRUPTS CAUSE NOISE
2020-09-29 turned on serial interrupts - required LOOPER_LOG() in loopMachine::command()
2020-10-29 added 3D printing files
    [Looper1.f3d, box.3mf, box.stl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]
2023-09-08 made ERASE_TRACK command on selected, but not running track, unselect it, cancel the pending command, and select the running track, if any
2024-04-25 changed printf() calls to LOG calls
2024-04-29 FIXED THE CRACKLY NOISE - which was caused by ILIBASE using gpio24 for the LCD_CD and conflicted with the OCTO hardwired use of that pin for setup OCTO_MULT3
2024-04-29 Increase loop buffer from 127M to 170M (60 seconds per track/clip)
2024-12-12 rework LooperBox from fusion to print ...
    [Looper1.f3d, box.3mf, box.stl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]
2024-12-12 add Looper Box Fusion Redraw f3d file
    [2024-12-09-LooperRedraw.f3d]
2025-01-05 rebuild Looper2 - fix minor 3DP issues
    [2025-01-04-LooperRedraw.f3d, box.3mf, box.stl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]
2025-01-12 set #define USE_STGL5000=0 and USE_CS42448=1 for (old) TeensyExpression rebuilds
2025-01-17 made new USBA board for Looper box
    [2025-01-17-LooperRedraw.f3z, USBA_TEMP_BASE.3mf, USBA_TEMP_BASE.stl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]
2025-03-05 START INTEGRATED TE3 mother_board testing - got the rPi display and com port basically working - discovered I had left the circle stuff in odd shape (460800 using OCTO audio device even with LOOPER3 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
2025-03-05 added rudimentary RPI_BUSY LED when uiWindow receives serial midi
2025-03-11 replaced little guitar input Pad PCB that had a switch with a new PCB with no switch
    [pad_switch.kicad_pcb, pad_switch.sch]
2025-03-11 check in TE3, TE3_audo, circle/_prh, and _apps/Looper after initial TE3 integration success. - rotaries don't work - only very few USBC cables work on the iPad, but strangely those that do, also work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
